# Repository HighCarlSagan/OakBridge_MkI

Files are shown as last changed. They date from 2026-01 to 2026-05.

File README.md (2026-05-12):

# OakBridge MkI

**A tactile PC dashboard — ESP32-S3, mechanical keys, IPS display, and a wooden enclosure.**







<p align="center">
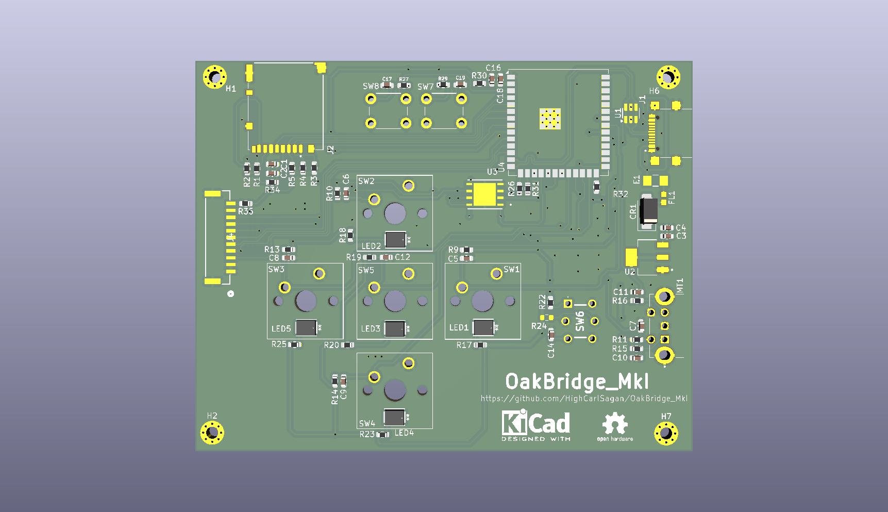
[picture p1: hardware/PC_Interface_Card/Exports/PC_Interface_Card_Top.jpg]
OakBridge MkI PCB - top view
  
  &nbsp;
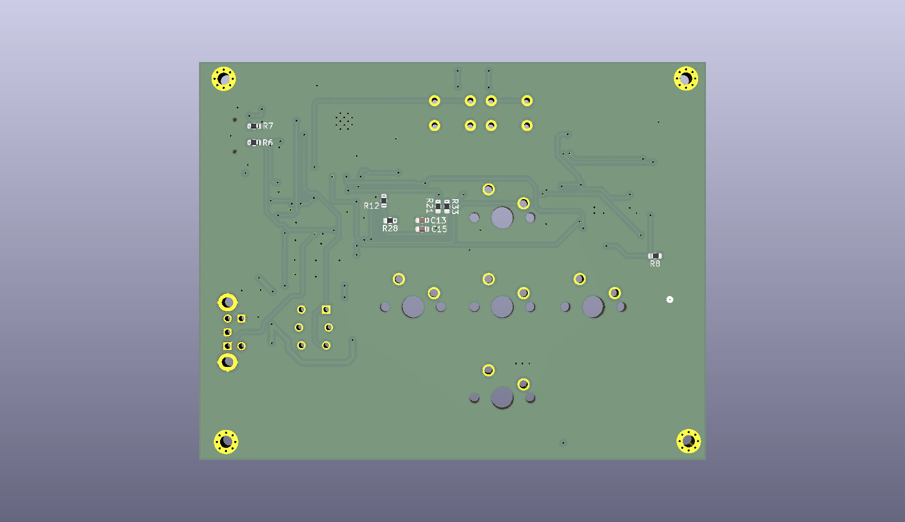
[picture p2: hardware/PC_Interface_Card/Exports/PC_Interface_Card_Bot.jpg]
OakBridge MkI PCB - bottom view
  
</p>

---

## Why I Built This

I spend a lot of my day staring at terminals and dashboards. I wanted a small, tactile thing on the desk that could show me what my PC was doing without me having to alt-tab to find out — CPU temp during a long compile, what's playing on Spotify, calendar at a glance — and let me poke at it with real keys instead of yet another window.

The other half of the motivation is the stretch. OakBridge is the first project where I deliberately scoped a hardware → firmware → host-software stack end-to-end, all on parts I hadn't used in anger before: ESP32-S3, LVGL on a real display, FRAM for state, and a Python companion talking over MQTT. The point is to do the whole loop once, badly, and have a tangible thing on the desk afterwards.

The name is a nod to **oak wood** (the planned enclosure) and a small shout-out to **Oak Ridge National Laboratory**.

---

## Initial Requirements

The table below tracks the design intent against what will ship on **v1.1** (the DRC-fixed respin currently in fab, expected back end of May 2026). The first soldered board — **v1.0** — never powered up; see [Lessons Learned](#lessons-learned-the-0mm-via-incident) for the story. Until v1.1 lands, all power-up-dependent outcomes are honestly marked **TBD**.

| # | Requirement | Target | Outcome (v1.1) |
|---|---|---|---|
| 1 | MCU with WiFi + BLE + USB + enough headroom for LVGL | ESP32-S3 class | ✅ ESP32-S3-WROOM-1-N16R8 (16 MB flash, 8 MB PSRAM) |
| 2 | Display | ≥3" IPS, ≥320×240, SPI | ✅ Waveshare 3.5" IPS 320×480 (touch fanned out but unused in MkI) |
| 3 | Tactile input | Real mechanical keys with backlighting | ✅ 5× Cherry MX2A-E1NA + per-key backlight LEDs |
| 4 | Analog input | Rotary encoder with push | ✅ CUI ACZ11 (12 PPR, integrated switch) |
| 5 | Non-volatile state across reboots | FRAM, ≥1 Mbit | ✅ MB85RS4MTYPN (4 Mbit SPI FRAM) |
| 6 | Local storage for assets / logs | MicroSD socket | ✅ Hirose DM3BT push-push socket |
| 7 | Single-cable host connection | USB-C, power + serial | ✅ USB-C 2.0 + CDC-ACM virtual COM |
| 8 | Front-end protection | ESD + reverse-polarity + EMI filtering + fuse | ✅ USBLC6-2SC6 + SS14 + BLM18PG600 + 1.5A fuse |
| 9 | Power | USB 5V in, single 3.3V rail | ✅ TLV1117LV33 LDO (1A capacity, ~400 mA budget) |
| 10 | Board size | Comfortably hand-held footprint | ✅ 92 × 70 mm, 2-layer FR-4 |
| 11 | Manufacturability | Common SMD, hand-solderable | ✅ 0603 passives, QFN regulator, through-hole switches |
| 12 | Power-on bring-up | All rails verified | ⏳ TBD (waiting on v1.1) |
| 13 | Display, switches, encoder, FRAM verified | Hardware sign-off | ⏳ TBD |
| 14 | Firmware: LVGL, MQTT, OTA, mDNS | End-to-end on real board | ⏳ TBD |
| 15 | Wooden enclosure | Oak / walnut, parametric CAD | 🔄 In progress, on backburner |

---

## Specifications

| | |
|---|---|
| **MCU** | Espressif ESP32-S3-WROOM-1-N16R8 (Xtensa LX7 dual-core, 16 MB flash, 8 MB PSRAM) |
| **Display** | Waveshare 3.5" IPS, 320 × 480, SPI (touch fanned out, not wired up in firmware) |
| **Keys** | 5 × Cherry MX2A-E1NA, per-key blue backlight (Cree JE2835) |
| **Encoder** | CUI ACZ11BR1E-15KQA1-12C, 12 PPR with push |
| **NV storage** | MB85RS4MTYPN — 4 Mbit SPI FRAM |
| **Removable storage** | Hirose DM3BT-DSF-PEJS — push-push microSD socket |
| **Host interface** | USB-C 2.0, power + CDC-ACM serial |
| **Front-end protection** | 1.5 A fuse → SS14 reverse-polarity Schottky → BLM18PG600 ferrite → USBLC6-2SC6 ESD array |
| **Regulator** | TI TLV1117LV33 — 3.3 V LDO, 1 A capacity |
| **Power budget** | ~400 mA typical (estimate; bring-up will measure) |
| **PCB** | 92 × 70 mm, 2-layer FR-4, 1.6 mm, 1 oz copper, ENIG |
| **Aux switches** | BOOT + EN (ESP32 strap-pull), one extra tactile for firmware-defined use |
| **Mounting** | 4 × M3 holes (H1, H2, H6, H7) |

---

## Architecture

```
                ┌──────────────────────────────────────────────┐
                │                  USB-C (J1)                  │
                │      5 V power + USB 2.0 (D+ / D−)           │
                └──────────────────┬───────────────────────────┘
                                   │
                          ┌────────┴───────────────┐
                          │  Protection front-end  │
                          │  Fuse → SS14 → Ferrite │
                          │     → USBLC6 ESD       │
                          └────────┬───────────────┘
                                   │ 5 V
                          ┌────────┴────────┐
                          │   TLV1117LV33   │
                          │   5 V → 3.3 V   │
                          └────────┬────────┘
                                   │ 3.3 V (1 A)
                                   │
        ┌──────────────────────────┼──────────────────────────┐
        │                          │                          │
        ▼                          ▼                          ▼
┌────────────────┐       ┌─────────────────────┐    ┌───────────────────┐
│ ESP32-S3 N16R8 │       │  Waveshare 3.5" IPS │    │  MB85RS4MTYPN     │
│  WiFi + BLE    │◀─────▶│   320×480, SPI      │    │  4 Mbit SPI FRAM  │
│  USB-OTG       │       │   JST-GH 11-pin (J4)│    │   (state, config) │
└───┬────────┬───┘       └─────────────────────┘    └───────────────────┘
    │        │
    │        │            ┌──────────────────────┐
    │        ├──────────▶ │  microSD (DM3BT, J2) │
    │        │            │  logs, assets        │
    │        │            └──────────────────────┘
    │        │
    │        │            ┌──────────────────────┐
    │        └──────────▶ │  5 × Cherry MX2A     │
    │                     │  + 5 × backlight LEDs│
    │                     │  + CUI ACZ11 encoder │
    │                     │  + BOOT / EN / aux   │
    │                     └──────────────────────┘
    │
    ▼   (over WiFi)
┌──────────────────────────────┐
│  PC companion (Python)       │
│  CPU / GPU / RAM / media     │
│  → MQTT broker → OakBridge   │
└──────────────────────────────┘
```

---

## Why X over Y

A handful of decisions on this board that had real alternatives. Capturing them here so future-me remembers the trade.

**ESP32-S3 over ESP32 / RP2040.** The S3 has native USB (no CH340), enough SRAM + PSRAM to make LVGL pleasant, hardware vector ops, and WiFi + BLE on-chip. RP2040 would have been cheaper and easier to program but every wireless feature would have become a bolt-on. ESP32 (original) lacks native USB and is starting to feel its age for new designs.

**FRAM over EEPROM or flash-only.** State on this board (last screen, brightness, key bindings, MQTT credentials) gets written often enough that flash endurance is a real concern, and EEPROM is too small / too slow for anything beyond a few config bytes. FRAM is essentially RAM-fast, byte-writable, and rated for 10¹³ writes. Worth the few extra dollars.

**MicroSD + FRAM, not just FRAM.** FRAM holds *state*; SD holds *content* (UI assets, fonts, logs, image slideshow). Different access patterns, different lifetimes, different sizes. Keeping them separate keeps the firmware honest about what's small-and-precious vs. large-and-replaceable.

**TLV1117LV33 LDO over a buck.** Total budget is ~400 mA at 3.3 V from a 5 V source. Worst-case dissipation is (5 − 3.3) × 0.4 ≈ 0.7 W — comfortable for a SOT-223 with a copper pour. A buck would have been ~10–15% more efficient at the cost of switching noise on the analog encoder input, a bigger BOM, and an inductor. Not worth it at this current.

**2-layer board, not 4-layer.** Cheap to fab and the signal count is low enough to route on two layers without pain. The trade I made — and paid for — was that USB differential routing on a 2-layer stackup is fussier than I respected. See [Lessons Learned](#lessons-learned-the-0mm-via-incident). MkII may go 4-layer just for the routing comfort, not because anything on this board needs it electrically.

**Cherry MX2A over original MX.** The MX2A generation has smoother factory lubing and a quieter sound profile, and the footprint is drop-in compatible with classic MX. Same keycap ecosystem, slightly nicer feel.

**Touch fanned out but unused.** The Waveshare 3.5" comes with capacitive touch on the same FPC. I fanned the touch lines out to the connector but didn't wire them into firmware for MkI. Wanted to keep the firmware scope tractable; physical keys are the primary interaction. Touch becomes a v2 / MkII concern.

---

## Key Components

| Ref | Part | Function |
|---|---|---|
| U4 | ESP32-S3-WROOM-1-N16R8 | MCU + WiFi/BLE module |
| U3 | MB85RS4MTYPN-GS | 4 Mbit SPI FRAM |
| U2 | TLV1117LV33DCYR | 3.3 V / 1 A LDO |
| U1 | USBLC6-2SC6 | USB ESD protection array |
| J1 | GSB1C41110SSHR | USB Type-C 2.0 receptacle (Amphenol) |
| J2 | DM3BT-DSF-PEJS | Push-push microSD socket (Hirose) |
| J4 | BM11B-GHS-TBT | JST GH 11-pin (display FPC fanout) |
| MT1 | ACZ11BR1E-15KQA1-12C | CUI rotary encoder, 12 PPR + push |
| SW1–SW5 | Cherry MX2A-E1NA | Mechanical key switches |
| SW6 | TL1240YQ2JBLK | Auxiliary tactile (firmware-defined) |
| SW7, SW8 | SW_Push (THT) | ESP32 BOOT and EN |
| LED1–LED5 | Cree JE2835ARY-N | Per-key backlight (blue) |
| CR1 | SS14 | Schottky reverse-polarity protection |
| F1 | 1.5 A fuse (C1Q-series) | Input over-current |
| FL1 | BLM18PG600SN1D | EMI ferrite bead |
| R6, R7 | 5.1 kΩ | USB-C CC pull-downs (UFP role) |
| R30, R33–R35 | 0 Ω | Config straps (boot mode / interface selection) |

Full BOM: [`hardware/PC_Interface_Card/Exports/PC_Interface_Card.csv`](hardware/PC_Interface_Card/Exports/PC_Interface_Card.csv)
Netlist: [`hardware/PC_Interface_Card/Exports/PC_Interface_Card.net`](hardware/PC_Interface_Card/Exports/PC_Interface_Card.net)

---

## Connector Pinout

| Connector | Type | Purpose |
|---|---|---|
| J1 — USB-C | Amphenol GSB1C41110SSHR | 5 V power in + USB 2.0 data (UFP, CC pull-downs to GND via 5.1 kΩ) |
| J2 — microSD | Hirose DM3BT push-push | SPI to ESP32 (CD line wired) |
| J4 — Display | JST GH 11-pin | SPI MOSI/SCLK + DC/CS/RST + backlight enable + touch (unused) |
| MT1 — Encoder | Through-hole | A / B / SW pins (pull-ups on host side) |
| H1 / H2 / H6 / H7 | M3 mounting | Mechanical only |

Detailed pin-by-pin mapping will live in [`docs/pinout.md`](docs/pinout.md) once firmware development starts and pin assignments are locked.

---

## Firmware

**Status: not started.** Waiting for v1.1 boards to arrive before writing a single line. The plan below is the design intent, not a description of code that exists.

**Framework:** ESP-IDF v5.x
**Location:** `firmware/` (currently empty)

**Planned scope:**

- **Display:** LVGL on top of the Waveshare SPI driver, double-buffered, target 30+ FPS on simple screens.
- **Input:** software-debounced switches; quadrature decode for the encoder; long-press / multi-press detection.
- **Storage:** FRAM holds runtime config (brightness, current screen, key bindings, MQTT credentials). microSD holds fonts, icons, and any image assets.
- **Connectivity:** WiFi station mode, mDNS responder as `oakbridge.local`, MQTT client to a user-configured broker, embedded HTTP config server, OTA over WiFi.
- **PC link:** MQTT topics — `oakbridge/stats` (incoming PC metrics), `oakbridge/media` (now-playing), `oakbridge/commands` (outgoing key/encoder events). QoS 1.

Firmware build and flash instructions will land in [`docs/firmware_guide.md`](docs/firmware_guide.md) (planned).

### PC Companion

**Status: placeholder.** No code yet. The repo has a `companion/` directory reserved for it.

**Plan:** Python 3.8+ daemon that collects CPU / GPU / RAM / temperature stats via `psutil` and `pynvml`, reads media-player state via MPRIS on Linux, and publishes everything to MQTT for OakBridge to render. Linux first (my daily driver); Windows / macOS later if there's appetite.

---

## Setup & Bring-up

(Filled in after v1.1 boards arrive and bring-up completes.)

**Planned bring-up sequence:**

| Step | Action | Pass criterion |
|---|---|---|
| 1 | Power on via USB-C, no MCU loaded | 3.3 V rail measures 3.27–3.33 V, no thermal events |
| 2 | Probe ESP32 strap pins at reset | BOOT/EN behave correctly, no unexpected boot mode |
| 3 | Flash a minimal "hello UART" firmware | CDC-ACM enumerates, serial output visible |
| 4 | LED smoke test | Each of LED1–LED5 lights when driven |
| 5 | Switch + encoder smoke test | All 5 MX keys + encoder A/B/SW register |
| 6 | FRAM read/write test | Known-pattern write → power cycle → read back matches |
| 7 | microSD enumerate + read | FAT32 mount succeeds, files listable |
| 8 | Display init | Waveshare 3.5" shows colour bars |
| 9 | LVGL "hello" screen | First UI screen renders, encoder navigates |
| 10 | WiFi join + MQTT publish loop | `oakbridge/heartbeat` visible on broker |

Empty results table for backfill once boards arrive:

| Step | Result | Date | Notes |
|---|---|---|---|
| 1 | TBD | | |
| 2 | TBD | | |
| 3 | TBD | | |
| 4 | TBD | | |
| 5 | TBD | | |
| 6 | TBD | | |
| 7 | TBD | | |
| 8 | TBD | | |
| 9 | TBD | | |
| 10 | TBD | | |

---

## Hardware

**KiCad project:** [`hardware/PC_Interface_Card/`](hardware/PC_Interface_Card/) (KiCad 9.0)
**Schematic PDF:** [`hardware/docs/schematic.pdf`](hardware/docs/schematic.pdf)
**Gerbers:** [`hardware/PC_Interface_Card/Exports/Gerbers/`](hardware/PC_Interface_Card/Exports/Gerbers/) (v1.1, planned for end-of-May 2026)
**BOM:** [`hardware/PC_Interface_Card/Exports/PC_Interface_Card.csv`](hardware/PC_Interface_Card/Exports/PC_Interface_Card.csv)

### PCB Specifications

- **Size:** 92 × 70 mm
- **Layers:** 2-layer FR-4, 1.6 mm
- **Copper:** 1 oz (35 µm) outer
- **Finish:** ENIG
- **Min trace / clearance:** 0.15 mm / 0.15 mm (6 mil / 6 mil)
- **USB differential pair:** 0.35 mm width, 0.15 mm gap, target 90 Ω
- **Vias (v1.1):** 0.6 mm pad / 0.3 mm drill (signal); 0.8 mm / 0.4 mm (power)
- **Stitching:** ~50 GND vias

Design rule references:
- [`hardware/docs/pcb_design_rules.md`](hardware/docs/pcb_design_rules.md)
- [`hardware/docs/usb_routing_quick_ref.txt`](hardware/docs/usb_routing_quick_ref.txt)
- [`hardware/docs/kicad_design_rules.json`](hardware/docs/kicad_design_rules.json)

### Enclosure

A wooden enclosure (oak) is planned. CAD work is in progress and on the backburner while the v1.1 PCB respin and firmware bring-up take priority. Parametric files will land in [`enclosure/`](enclosure/) once the design is ready.

---

## Lessons Learned: the 0mm-via incident

The v1.0 board does not work. It does not even power up — I haven't tried, because the failure is structural, not electrical.

**What happened.** When I set up the PCB design rules in KiCad, I left the **via drill diameter at 0 mm** in one of the via classes. KiCad's DRC would have caught this immediately. I skipped DRC verification before exporting Gerbers, because the layout was "obviously fine" — I had reviewed it visually and the renders looked clean. The fab took the files as-is, produced the board with pads where vias should have been, and shipped it. I soldered the whole thing before realising every via on the affected net class was just a copper dot with no hole through the board.

**What I'm doing about it.**

1. **v1.1 is in fab.** Same design, drill diameters corrected, going turnkey this time so I get a populated board back. Expected end of May 2026.
2. **DRC is no longer optional.** From now on, "DRC pass" is a step in my export checklist that has to be ticked before Gerbers leave my machine. I've added a one-line note to my KiCad project template.
3. **I review fab DFM reports.** Most fabs *do* run DFM checks and flag missing drills. This one didn't, or did and I missed the email. Either way, the responsibility is on me to verify, not on them to warn.

**Why this is in the README and not buried.** The whole point of these write-ups is to be honest about how the work actually went. The board is broken because I made an avoidable mistake. Documenting it costs me nothing and saves the next person (probably future-me, on a different project) from doing the same thing. It also makes everything *else* in this README more credible.

More detail in [`docs/lessons-learned.md`](docs/lessons-learned.md).

---

## Repository Structure

```
OakBridge_MkI/
├── hardware/
│   ├── PC_Interface_Card/         # KiCad 9.0 project
│   │   ├── PC_Interface_Card.kicad_pro
│   │   ├── PC_Interface_Card.kicad_sch
│   │   ├── PC_Interface_Card.kicad_pcb
│   │   ├── Libraries/             # Custom symbols + footprints
│   │   └── Exports/
│   │       ├── Gerbers/
│   │       ├── PC_Interface_Card.csv     # BOM
│   │       ├── PC_Interface_Card.net     # Netlist
│   │       ├── PC_Interface_Card_Top.jpg
│   │       └── PC_Interface_Card_Bot.jpg
│   └── docs/
│       ├── schematic.pdf
│       ├── pcb_design_rules.md
│       ├── usb_routing_quick_ref.txt
│       └── kicad_design_rules.json
├── firmware/                      # ESP-IDF project (planned)
├── companion/                     # Python PC companion (placeholder)
├── enclosure/                     # Oak enclosure CAD (in progress)
├── docs/
│   ├── lessons-learned.md
│   ├── firmware_guide.md          # planned
│   ├── pinout.md                  # planned
│   └── images/
├── LICENSE
└── README.md
```

---

## When to Use This / When NOT to Use This

**Use this if you want to:**
- Build a tactile, mechanical-key dashboard for your own PC, on your own desk, with your own UI.
- Learn ESP32-S3, LVGL, FRAM, and MQTT together on one small board.
- Fork the design as a starting point for any "small wireless gadget with a screen and a few buttons" project.

**Don't use this if you want to:**
- A polished, validated, production-ready product. This is a personal learning project. v1.0 didn't power up. v1.1 is in fab.
- A keyboard. 5 keys is not a keyboard. If you want a macropad, the Cherry MX footprints are reusable but you'd be better off with a project actually scoped as a macropad.
- A low-latency input device for gaming. USB-CDC + MQTT has latencies that are fine for "skip track" and bad for "fire weapon".

---

## Roadmap

### v1.0 — soldered, dud (May 2026)
PCBs fabricated and hand-soldered. Discovered the 0mm-via DRC miss after assembly. Never powered up. Kept on the desk as a reminder.

### v1.1 — DRC-fixed respin (end of May 2026, in fab)
- ✅ Drill diameters corrected, DRC clean, Gerbers re-exported
- ⏳ Turnkey assembly with the fab — boards arrive populated
- ⏳ Power-on bring-up (table above)
- ⏳ Firmware v0.1 — display init, switches, encoder, FRAM read/write
- ⏳ Firmware v0.2 — WiFi + MQTT + first PC-companion round-trip
- 🔄 Enclosure CAD (oak) — in progress, no committed date

### MkII — possibilities (much later, ~2027)

Not committed. Listing what I'd consider if I redesigned from scratch:

- 4-layer stackup for cleaner USB / display routing
- Capacitive touch wired into firmware (FPC fanout already exists)
- USB-C PD negotiation for higher current headroom
- Side-mount encoder for a flatter front face
- Independent RGB backlight per key (currently single-channel blue)

---

## License

**Hardware:** [CERN Open Hardware Licence Version 2 — Permissive (CERN-OHL-P-2.0)](LICENSE)
**Firmware** (when it exists): MIT
**Documentation:** CC-BY-4.0

You're free to use, modify, fabricate, and distribute the hardware design with attribution. No reciprocity required.

---

## Related Projects

- **[PC_and_Light_Controller](https://github.com/HighCarlSagan/PC_and_Light_Controller)** — sibling desk-control project. PC_and_Light_Controller handles physical switching of mains-powered desk devices; OakBridge handles the on-desk informational layer. Different problems, same desk.
- **[Dual_Power_Supply](https://github.com/HighCarlSagan/Dual_Power_Supply)** — my benchtop linear supply. The supply that probed v1.0 and confirmed the bad news.
- **[Carls_Homelab_Public](https://github.com/HighCarlSagan/Carls_Homelab_Public)** — where the MQTT broker will eventually live.

---

## Author

**Mayank S (HighCarlSagan)** — [GitHub @HighCarlSagan](https://github.com/HighCarlSagan) · [highcarlsagan.dev](https://highcarlsagan.dev)

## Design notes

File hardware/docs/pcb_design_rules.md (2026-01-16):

# OakBridge MkI PCB Design Rules & Guidelines

## Board Analysis Summary

### Key Components:
- **ESP32-S3-WROOM-1**: Main microcontroller (RF module)
- **USB-C Connector**: GSB1C41110SSHR (USB 2.0)
- **3.3V LDO**: TLV1117LV33 (1A)
- **FRAM**: MB85RS4MT (4Mbit SPI)
- **Display**: 3.5" Waveshare via 11-pin connector
- **Inputs**: 5x Cherry MX switches, rotary encoder, 3x tactile switches
- **LEDs**: 5x Cree JE2835 (with series resistors)
- **MicroSD**: Card connector

---

## LAYER STACK RECOMMENDATION: **2 LAYERS IS SUFFICIENT**

### Why 2 layers works:
✅ Single digital voltage domain (3.3V)
✅ Low-speed USB 2.0 (not high-speed USB)
✅ Low-frequency SPI communication (<50 MHz)
✅ No high-power analog circuits
✅ WiFi/BT RF contained within shielded module
✅ Good grounding achievable with careful ground plane design

### Cost-benefit:
- 2-layer: ~$5-20 for prototype (JLCPCB/PCBWay)
- 4-layer: ~$40-80 for same board
- No technical advantage justifies 4x cost increase for this design

---

## VIA SPECIFICATIONS

### Signal Vias (default):
- **Drill size**: 0.3mm (12 mil)
- **Annular ring**: 0.2mm (8 mil) minimum
- **Finished hole**: 0.3mm drill = ~0.28mm finished
- **Pad diameter**: 0.7mm (28 mil)
- **Use case**: All general signal routing

### Power Vias (USB +5V, +3.3V):
- **Drill size**: 0.4mm (16 mil)
- **Pad diameter**: 0.8mm (32 mil)
- **Quantity**: Multiple vias in parallel for power distribution
- **Spacing**: 2-3mm apart in power delivery paths
- **Use**: USB input, LDO output, ESP32 power pins

### Ground Stitching Vias:
- **Drill size**: 0.3mm (12 mil)
- **Pad diameter**: 0.7mm (28 mil)
- **Spacing**: Every 5-10mm along board perimeter
- **Quantity**: ~20-30 vias around board edge
- **Purpose**: Connect top/bottom ground planes, reduce EMI

### USB Shield Vias:
- **Drill size**: 0.5mm (20 mil)
- **Pad diameter**: 1.0mm (40 mil)
- **Placement**: 4x vias surrounding USB connector
- **Purpose**: Low impedance ground connection for shield

---

## TRACE WIDTH SPECIFICATIONS

### Power Traces:
```
+5V USB Input (up to 1A):
- Width: 0.6mm (24 mil) minimum
- Preferred: 0.8mm (32 mil)
- Temperature rise: <10°C @ 1A

+3.3V Rail (up to 800mA):
- Width: 0.5mm (20 mil) minimum
- Preferred: 0.6mm (24 mil)

LED Current (20-40mA per LED):
- Width: 0.2mm (8 mil) - adequate
- From resistors to LEDs
```

### Signal Traces:
```
Standard Digital I/O:
- Width: 0.15mm (6 mil) typical
- Spacing: 0.15mm (6 mil)
- SPI, I2C, GPIO: all 0.15mm is fine

High-frequency signals (if any):
- Width: 0.2mm (8 mil)
- Keep traces short
```

### Ground Planes:
```
- Pour on both layers
- Top layer: Split only where necessary
- Bottom layer: Solid continuous plane (ideal)
- Minimum clearance: 0.2mm (8 mil)
- Thermal relief: 0.5mm spoke width, 4 spokes
```

---

## USB 2.0 DIFFERENTIAL PAIR ROUTING

### USB D+/D- Specifications:
The USB-C connector provides USB 2.0 data:
- **Target impedance**: 90Ω differential (±10%)
- **Single-ended**: ~45Ω each

### Trace Dimensions (2-layer FR-4, 1.6mm thick):
```
Trace width: 0.35mm (14 mil)
Trace spacing (edge-to-edge): 0.15mm (6 mil)
Trace gap (center-to-center): 0.50mm (20 mil)
```

This achieves **~90Ω differential impedance** on standard FR-4:
- Er = 4.5
- H (dielectric height) = 1.6mm to bottom ground plane
- Calculate: Use Saturn PCB toolkit or KiCad calculator

### Critical USB Routing Rules:
1. **Keep D+ and D- paired**: Always route together
2. **Length matching**: ±2mm (±80 mil) maximum difference
3. **No vias if possible**: Route on single layer (top preferred)
4. **If vias needed**: Use both D+ and D- vias together, keep symmetrical
5. **Avoid 90° angles**: Use 45° or curved traces
6. **Keep away from**: 
   - Switching power traces (LDO input)
   - High-frequency digital signals (SPI CLK)
   - LED switching signals
7. **Ground reference**: Continuous ground plane underneath
8. **Trace length**: Keep <75mm (3 inches) total

### USB Connector Ground Strategy:
```
1. Four shield pins → direct via to ground plane (0.5mm vias)
2. GND pins → connect to ground pour
3. Add ground stitching vias around connector (every 2-3mm)
4. Ground guard traces on both sides of D+/D- pair
```

### Series Resistors (Already in schematic):
- **R6, R7**: 5.1kΩ on CC1, CC2 (correct for USB-C PD detection)
- Place **immediately adjacent** to USB connector
- No termination resistors needed on D+/D- for device-side

---

## COMPONENT-SPECIFIC LAYOUT GUIDELINES

### ESP32-S3-WROOM-1 Module:
```
Critical requirements:
1. Ground plane: Solid copper under entire module (both layers)
2. Keep-out zone: 15mm from antenna side (check datasheet)
3. Decoupling caps: Place C2, C4 as close as possible to 3V3 pin
4. SPI routing: Keep FRAM signals (CS, SCK, MOSI, MISO) <50mm
5. Boot/enable pullups: R1, R10 near module pins
```

### TLV1117LV33 LDO Regulator:
```
Input (VIN):
- C1 (1µF): Place <3mm from input pin
- Trace from USB: 0.6mm width minimum

Output (VOUT):
- C3 (1µF): Place <3mm from output pin
- Use multiple 0.4mm vias to distribute 3.3V

Ground:
- Large thermal pad on bottom layer
- Multiple vias (5-10x) connecting to bottom ground plane
- Thermal relief NOT recommended (need heat dissipation)
```

### USBLC6-2SC6 TVS Diode:
```
Placement:
- Must be between USB connector and ESP32
- Distance from USB connector: <10mm
- Route D+/D- through TVS before going to ESP32
- Ground pin: Direct via to ground plane (0.4mm via)

Routing:
  USB D+ → TVS I/O1 → ESP32 GPIO19
  USB D- → TVS I/O2 → ESP32 GPIO20
  TVS GND → Ground plane (low impedance)
```

### Cherry MX Switches (SW1-SW5):
```
Mechanical:
- Standard MX spacing: 19.05mm (0.75")
- PCB cutout: 14mm x 14mm
- Ensure adequate clearance for keycap travel

Electrical:
- Pull-up resistors: Already included (10kΩ)
- Debouncing: Software (GPIO inputs have hardware filters)
- Series resistors: 33Ω (R17, R19, R22, R23, R26) - correct!
```

### LED Routing:
```
Current-limiting resistors: 68Ω (R27, R30, R34) for 3 LEDs
                           33Ω for 2 LEDs (depends on color/current)

Placement:
- Resistor adjacent to LED (cathode side preferred)
- Trace width: 0.2mm adequate for <40mA
- Ground return: Use local ground plane
```

### MicroSD Card Slot:
```
SPI routing to ESP32:
- Keep all SPI traces <50mm
- Route on same layer (avoid vias)
- No need for matched lengths (low speed)
- Decoupling: C13 (1µF) near SD card power pin

Card detect switch:
- Pull-up already included in design
- Debounce in software
```

### Rotary Encoder (ACZ11BR1E):
```
Mounting:
- Through-hole component
- Ensure mechanical alignment with panel cutout

Routing:
- A, B, Common pins to ESP32 GPIOs
- Pull-ups: 10kΩ (R11, R12, R13)
- Shield connection: Ground via
- Debounce: Handle in firmware
```

---

## PCB DESIGN RULES (KiCad Settings)

### Design Rules → Constraints:
```
Minimum clearance: 0.15mm (6 mil)
Minimum track width: 0.15mm (6 mil)
Minimum via diameter: 0.7mm (28 mil)
Minimum via drill: 0.3mm (12 mil)
Minimum hole-to-hole: 0.5mm (20 mil)

Differential pairs (USB):
- Width: 0.35mm
- Gap: 0.15mm
- Max uncoupled: 0.5mm (design for 0.2mm)
```

### Design Rules → Pre-defined Sizes:
```
Via size #1 (Signal):
- Diameter: 0.7mm / Drill: 0.3mm

Via size #2 (Power):
- Diameter: 0.8mm / Drill: 0.4mm

Via size #3 (Ground stitching):
- Diameter: 0.7mm / Drill: 0.3mm

Track width #1 (Signal): 0.15mm
Track width #2 (Power 3.3V): 0.5mm
Track width #3 (Power 5V): 0.6mm
Track width #4 (USB diff): 0.35mm
```

### Board Setup → Physical Stackup:
```
2-Layer board:
- Total thickness: 1.6mm (standard)
- Copper weight: 1 oz (35µm) on both layers
- Core: FR-4 (Er ~4.5)
- Solder mask: Both sides (green/black/blue)
- Silkscreen: Both sides
- Surface finish: ENIG (gold) or HASL (lead-free)
```

### Solder Mask Expansion:
```
Solder mask expansion: 0.05mm (2 mil)
Solder paste shrinkage: 0.0mm (default)
Minimum web width: 0.1mm

For USB connector pads:
- Consider "solder mask defined" pads
- Prevents solder bridging on fine-pitch
```

---

## GROUNDING STRATEGY

### Two-Layer Ground Approach:
```
TOP LAYER (Component side):
- Ground pour with splits around:
  * USB differential pair
  * High-current power traces
  * RF antenna keep-out zone
- Connect pour to bottom ground with stitching vias

BOTTOM LAYER (Solder side):
- Solid continuous ground plane (IDEAL)
- No splits except for specific isolation
- Main return path for all signals
- ESP32 module sits over solid ground
```

### Ground Stitching Pattern:
```
Via placement:
1. Around board perimeter: Every 5-10mm
2. Under ESP32 module: 10-15 vias
3. Around USB connector: 6-8 vias
4. Between power sections: 3-5 vias
5. Near high-speed signals: Every 10mm along trace

Total ground vias: ~40-60 for typical board size
```

### Ground Connection Priority:
```
1. USB shield → Ground (0.5mm vias, 4x)
2. LDO thermal pad → Ground (0.4mm vias, 8x)
3. ESP32 GND pins → Ground (0.3mm vias, 4x)
4. Bypass cap grounds → Ground (0.3mm vias, 1-2x each)
5. Connector shields → Ground
```

---

## MANUFACTURING & ASSEMBLY NOTES

### Fabrication Specifications (JLCPCB/PCBWay):
```
Board size: Measure actual (likely <100x100mm)
Layers: 2
Thickness: 1.6mm
Min track/space: 6/6 mil (0.15/0.15mm)
Min hole size: 0.3mm
Copper weight: 1 oz
Surface finish: ENIG preferred (better for RF/USB)
Solder mask color: Your choice
Silkscreen: White on dark, black on light
```

### Panelization:
```
If ordering multiple boards:
- Add mouse bites or V-grooves
- Keep 5mm border around board edge
- Tooling holes: 4x at corners
```

### Assembly Recommendations:
```
1. Reflow profile for 0603 components: Standard SAC305
2. Stencil thickness: 0.12mm (standard)
3. Paste release: 1:1 ratio (stencil holes = pads)
4. Order: 
   a. Reflow SMD components
   b. Hand-solder through-hole (switches, encoder, connectors)
```

### Special Considerations:
```
- ESP32 module: Pre-assembled, reflow once only
- Cherry MX switches: Hand solder after SMD reflow
- USB-C connector: Verify alignment before soldering
- MicroSD slot: Correct orientation critical
- Display connector: Pin 1 alignment
```

---

## DESIGN RULE CHECK (DRC) SETTINGS

### Critical Checks:
```
✅ Clearance violations
✅ Track width violations
✅ Via size violations
✅ Hole-to-hole spacing
✅ Copper-to-edge clearance (0.5mm min)
✅ Silkscreen-to-pad clearance (0.15mm)
✅ Courtyard overlap (component collision)
✅ Unconnected pads
✅ Missing traces
```

### Electrical Rules Check (ERC):
```
✅ Power pins connected
✅ Pull-ups/downs present
✅ Unused inputs tied to valid logic levels
✅ Decoupling caps on all power pins
✅ Crystal loading caps (N/A - using internal oscillator)
✅ Reset/boot circuitry correct
```

---

## IMPEDANCE CALCULATIONS (Reference)

### USB Differential Impedance:
For 2-layer board (1.6mm FR-4, 1oz copper):
```
W = 0.35mm (trace width)
S = 0.15mm (edge-to-edge spacing)
H = 1.6mm (height to ground plane)
Er = 4.5 (FR-4)

Calculated Zdiff ≈ 88-92Ω ✅ (target: 90Ω ±10%)
```

Verify using:
- KiCad PCB Calculator (Tools → Calculator)
- Saturn PCB Toolkit
- Online calculator: https://www.eeweb.com/tools/differential-stripline-impedance/

---

## TESTING & VALIDATION CHECKLIST

### Pre-Assembly Tests:
```
□ Visual inspection: No short circuits, clean pads
□ Continuity test: Power rails isolated from ground
□ USB connector: No shorts between D+, D-, VBUS, GND
```

### Post-Assembly Tests:
```
□ Power-on test: Measure 5V at USB input
□ LDO output: Verify 3.3V ±3%
□ ESP32 boot: Check via serial (EN button + GPIO0)
□ USB enumeration: Device appears on PC
□ LED test: All LEDs functional
□ Switch test: All switches register
□ MicroSD: Card detect and SPI communication
□ Display: SPI communication and display init
□ Encoder: A/B phase signals
```

---

## RECOMMENDED LAYOUT WORKFLOW

1. **Placement** (Most critical step):
   - USB connector on board edge
   - ESP32 in center region
   - LDO near USB input
   - TVS diode between USB and ESP32
   - MicroSD slot near ESP32 SPI pins
   - Switches arranged ergonomically
   - LEDs visible from front panel

2. **Power routing** (Do this first):
   - 5V from USB to LDO input
   - 3.3V from LDO to all components
   - Multiple vias for power distribution
   - Ground plane on both layers

3. **Critical signal routing**:
   - USB D+/D- differential pair (0.35mm, 0.15mm gap)
   - SPI signals (FRAM, MicroSD)
   - Display connector signals

4. **General signals**:
   - Switch inputs
   - LED outputs
   - Encoder signals

5. **Ground plane pour**:
   - Top layer: Pour with keepouts
   - Bottom layer: Solid pour
   - Add stitching vias (~50 total)

6. **Silkscreen**:
   - Component references
   - Pin 1 indicators
   - Polarity markers
   - Version number
   - Your logo/name

7. **Final checks**:
   - DRC: Zero errors
   - Visual inspection
   - 3D view verification
   - Gerber preview

---

## COST ESTIMATES (2025 Prices)

### PCB Fabrication:
```
2-layer, 100x100mm, 1.6mm, ENIG:
- JLCPCB: $5 for 5 boards + shipping (~$20-30 total)
- PCBWay: Similar pricing
- OSH Park: ~$5/sq.in × area (~$25-35 total)

Turnaround:
- Standard: 7-10 days
- Express: 3-5 days (+50% cost)
```

### Component Assembly (if using JLCPCB):
```
Basic SMD assembly: ~$15-30
+ Extended parts library: +$3/part type
+ Setup fee: $8
Total BOM cost: ~$50-80 (depends on parts)

Hand assembly recommended for this design:
- Through-hole switches
- Display connector
- USB connector (easier by hand)
```

---

## FILES TO GENERATE FOR MANUFACTURING

### Required Gerber Files:
```
- F.Cu (Top copper)
- B.Cu (Bottom copper)
- F.Mask (Top solder mask)
- B.Mask (Bottom solder mask)
- F.Silkscreen (Top silkscreen)
- B.Silkscreen (Bottom silkscreen)
- Edge.Cuts (Board outline)
- F.Paste (Top solder paste)
- B.Paste (Bottom solder paste)

Drill files:
- .drl (Excellon drill file)
- PTH and NPTH separate or combined
```

### Additional Files:
```
- BOM (CSV or Excel)
- CPL/PnP (Pick-and-place coordinates)
- Assembly drawing (PDF)
- Schematic (PDF)
- 3D model (STEP file - for enclosure design)
```

---

## FINAL RECOMMENDATIONS

### For your OakBridge MkI design:

✅ **Use 2 layers** - No technical need for 4 layers
✅ **Standard vias** (0.7mm/0.3mm drill) work fine
✅ **USB impedance**: 0.35mm traces, 0.15mm gap → 90Ω
✅ **Power traces**: 0.5-0.6mm adequate for currents involved
✅ **Ground plane**: Bottom layer solid, top layer poured
✅ **Total cost**: ~$30-50 for 5 prototype boards

### Next Steps:
1. Apply these design rules in KiCad
2. Complete component placement
3. Route critical signals (USB, power, SPI)
4. Route remaining signals
5. Pour ground planes
6. Add ground stitching vias
7. Run DRC (fix all errors)
8. Generate Gerbers
9. Order from JLCPCB/PCBWay

Good luck with your layout! 🚀

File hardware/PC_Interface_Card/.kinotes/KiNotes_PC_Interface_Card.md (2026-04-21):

# **PC_Interface_Card - Design Notes**

## **Overview**
<!-- Brief description of the PCB project -->

## **Schematic Notes**
<!-- Key circuit blocks, design rationale -->

## **Layout Considerations**
<!-- Layer stackup, impedance, keep-outs -->

## **Component Notes**
<!-- Click on designators like R1, C5, U3 to highlight on PCB -->

## **Power Distribution**
<!-- Power rails, decoupling strategy -->

## **Signal Integrity**
<!-- Critical nets, routing constraints -->

## **References**
<!-- Datasheets, application notes, calculations -->

---
*KiNotes - PCBtools.xyz*

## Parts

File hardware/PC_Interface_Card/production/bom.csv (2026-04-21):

Designator | Footprint | Quantity | Value | LCSC Part #
C1, C13, C16, C3 | 0603 | 4 | 1u_50V_0603 | C15849
C10, C11, C12, C14, C15, C17, C18, C19, C2, C4, C5, C6, C7, C8, C9 | 0603 | 15 | 100n_50V_0603 | C14663
CR1 | D_SMA | 1 | SS14 | C2480
F1 | C1_BEL-M | 1 | C1Q 1.5
FL1 | BEAD_BLM18PG_C1608X95N | 1 | BLM18PG600SN1D
J1 | AMPHENOL_GSB1C41110SSHR | 1 | GSB1C41110SSHR
J2 | HRS_DM3BT-DSF-PEJS | 1 | DM3BT-DSF-PEJS
J4 | CONN11_BM11B-GHS-TBTLFSNN_JST | 1 | BM11B-GHS-TBT
LED1, LED2, LED3, LED4, LED5 | LED_JE2835_CRW-M | 5 | LED_Cree_JE2835
MT1 | XDCR_ACZ11BR1E-15KQA1-12C | 1 | ACZ11BR1E-15KQA1-12C
R1, R10, R11, R12, R13, R14, R15, R16, R19, R2, R21, R22, R26, R27, R28, R29, R3, R31, R32, R4, R5, R8, R9 | 0603 | 23 | 10k_0.1W_0603 | C25804
R17, R18, R20, R23, R25 | 0603 | 5 | 33R_0.1W_0603 | C23140
R24 | 0603 | 1 | 68R_0.2W_0603
R30, R33, R34, R35 | 0603 | 4 | 0R_0.1W_0603 | C21189
R6, R7 | 0603 | 2 | 5.1k_0.1W_0603 | C23186
SW1, SW2, SW3, SW4, SW5 | CherryMX_1.00u_PCB | 5 | CherryMX
SW6 | TL1240YQ | 1 | TL1240YQ2JBLK
SW7, SW8 | SW_PUSH_6mm | 2 | SW_Push
U1 | SOT-23-6 | 1 | USBLC6-2SC6
U2 | VREG_TLV1117LV33DCYR | 1 | TLV1117LV33DCYR
U3 | DFN8_FUJ-M | 1 | MB85RS4MTYPN-GS-AWEWE1
U4 | ESP32-S3-WROOM-1U | 1 | ESP32-S3-WROOM-1 | C2913202

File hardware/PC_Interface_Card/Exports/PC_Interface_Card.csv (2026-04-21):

Reference | Qty | Value | DNP | Exclude from BOM | Exclude from Board | Footprint | Datasheet | Manufacturer | Manufacturer Part Number | Description | LCSC
C1,C3,C13,C16 | 4 | 1u_50V_0603 |  |  |  | Capacitor_SMD:C_0603_1608Metric | https://jlc-prod-smt.oss-eu-central-1.aliyuncs.com/smtDataManualFile/8556213788455567360-C15849.pdf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 | KEMET | C0603C105K4RACTU | 1uF 50V X5R ±10% 0603 Multilayer Ceramic Capacitors MLCC - SMD/SMT ROHS | C15849
C2,C4,C5,C6,C7,C8,C9,C10,C11,C12,C14,C15,C17,C18,C19 | 15 | 100n_50V_0603 |  |  |  | Capacitor_SMD:C_0603_1608Metric | https://jlc-prod-smt.oss-eu-central-1.aliyuncs.com/smtDataManualFile/8556213788455567360-C15849.pdf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 | YAGEO | CC0603KRX7R7BB104 | 100nF 50V X7R ±10% 0603 Multilayer Ceramic Capacitors MLCC - SMD/SMT ROHS | C14663
CR1 | 1 | SS14 |  |  |  | Diode_SMD:D_SMA | https://jlc-prod-smt.oss-eu-central-1.aliyuncs.com/smtDataManualFile/8579710789134958592-C2480.pdf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 | Onsemi | SS14 | -55℃~+150℃ 1A 25A 300uA@40V 40V 550mV@1A Independent SMA(DO-214AC) Schottky Diodes ROHS | C2480
F1 | 1 | C1Q 1.5 | DNP |  |  | Footprint:C1_BEL-M | https://www.digikey.in/en/products/detail/bel-fuse-inc/C1Q-1-5/615158 | Bel Fuse | C1Q 1.5 | 1.5 A 125 V 63 V Fuse Board Mount (Cartridge Style Excluded) Surface Mount 1206 (3216 Metric)
FL1 | 1 | BLM18PG600SN1D | DNP |  |  | Footprint:BEAD_BLM18PG_C1608X95N | https://www.murata.com/en-us/products/productdata/8796738650142/ENFA0003.pdf | Murata | BLM18PG600SN1D | 60 Ohms @ 100 MHz 1 Power Line Ferrite Bead 0603 (1608 Metric) 500mA 100mOhm
J1 | 1 | GSB1C41110SSHR | DNP |  |  | Footprint:AMPHENOL_GSB1C41110SSHR | https://cdn.amphenol-cs.com/media/wysiwyg/files/documentation/datasheet/inputoutput/io_usb_2_0_type_c_lite.pdf | Amphenol | GSB1C41110SSHR | USB-C (USB TYPE-C) USB 2.0 Receptacle Connector 24 (16+8 Dummy) Position Surface Mount, Right Angle; Through Hole
J2 | 1 | DM3BT-DSF-PEJS | DNP |  |  | Footprint_Project_PC_Interface:HRS_DM3BT-DSF-PEJS | https://www.hirose.com/product/download/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 | Hirose | DM3BT-DSF-PEJS | 10 (8 + 2) Position Card Connector Secure Digital - microSD™ Surface Mount, Right Angle Gold
J3,J5 | 2 | GHR-11V-S | DNP |  | Excluded from board |  | https://www.jst-mfg.com/product/pdf/eng/eGH.pdf | JST Sales America Inc. | GHR-11V-S | 11 Rectangular Connectors - Housings Receptacle Natural 0.049" (1.25mm)
J4 | 1 | BM11B-GHS-TBT | DNP |  |  | Footprint_Project_PC_Interface:CONN11_BM11B-GHS-TBTLFSNN_JST |  | JST Sales America Inc. | BM11B-GHS-TBT | Generic connector, single row, 01x13, script generated
LED1,LED2,LED3,LED4,LED5 | 5 | LED_Cree_JE2835 |  |  |  | Footprint:LED_JE2835_CRW-M | https://downloads.cree-led.com/files/ds/j/JSeries-2835-Color.pdf | Cree LED | JE2835ARY-N-0002A0000-N0000001 | LED Lighting Color J Blue 455nm (450nm ~ 460nm) 1411 (3528 Metric)
MD1 | 1 | WaveShare 3.5" RPi LCD (G) | DNP |  | Excluded from board |  | https://www.waveshare.com/wiki/3.5inch_RPi_LCD_(G) | Waveshare | 30897 | 3.5inch Resistive Touch Display (G) for Raspberry Pi, IPS Panel, 320×480 Resolution, Immersion Gold Process, 262K Color
MK1 | 1 | OEDNI-75-4-7 | DNP |  | Excluded from board |  | https://static1.squarespace.com/static/54efb6f4e4b0d7862a93d7f5/t/57b3baa8cd0f68856d468c76/1471396521494/OED_PNB_fv3_v.png | Kilo International | OEDNI-75-4-7 | Knurled, Diamond Knob 0.236" (6.00mm) Shaft with Metal Black Matte
MT1 | 1 | ACZ11BR1E-15KQA1-12C | DNP |  |  | Footprint:XDCR_ACZ11BR1E-15KQA1-12C | https://www.cuidevices.com/product/resource/acz11.pdf | Same Sky (Formerly CUI Devices) | ACZ11BR1E-15KQA1-12C | Rotary Encoder Incremental 12 Quadrature (Incremental) Right Angle
R1,R2,R3,R4,R5,R8,R9,R10,R11,R12,R13,R14,R15,R16,R19,R21,R22,R26,R27,R28,R29,R31,R32 | 23 | 10k_0.1W_0603 |  |  |  | Resistor_SMD:R_0603_1608Metric | https://jlc-prod-smt.oss-eu-central-1.aliyuncs.com/smtDataManualFile/8579706381316128768-C25804.pdf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 | Panasonic Electronic Components | ERJ-PB3B1002V | -55℃~+155℃ 100mW 10kΩ 75V Thick Film Resistor ±1% ±100ppm/℃ 0603 Chip Resistor - Surface Mount ROHS | C25804
R6,R7 | 2 | 5.1k_0.1W_0603 |  |  |  | Resistor_SMD:R_0603_1608Metric | https://jlc-prod-smt.oss-eu-central-1.aliyuncs.com/smtDataManualFile/8579706277020426240-C23186.pdf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 | Panasonic Electronic Components | ERJ-PB3B5101V | -55℃~+155℃ 100mW 5.1kΩ 75V Thick Film Resistor ±1% ±100ppm/℃ 0603 Chip Resistor - Surface Mount ROHS | C23186
R17,R18,R20,R23,R25 | 5 | 33R_0.1W_0603 |  |  |  | Resistor_SMD:R_0603_1608Metric | https://jlc-prod-smt.oss-eu-central-1.aliyuncs.com/smtDataManualFile/8579706226135130112-C23140.pdf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 | TE Connectivity Passive Product | CRGH0603J33R | -55℃~+155℃ 100mW 33Ω 75V Thick Film Resistor ±1% ±100ppm/℃ 0603 Chip Resistor - Surface Mount ROHS | C23140
R24 | 1 | 68R_0.2W_0603 | DNP |  |  | Resistor_SMD:R_0603_1608Metric | https://www.yageogroup.com/content/datasheet/asset/file/PYU-RC_GROUP_51_ROHS_L | YAGEO | RC0603FR-7W68RL | 68 Ohms ±1% 0.2W, 1/5W Chip Resistor 0603 (1608 Metric) Moisture Resistant Thick Film
R30,R33,R34,R35 | 4 | 0R_0.1W_0603 |  |  |  | Resistor_SMD:R_0603_1608Metric | https://jlc-prod-smt.oss-eu-central-1.aliyuncs.com/smtDataManualFile/8578255895085699072-C21189.pdf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 |  |  | -55℃~+155℃ 0Ω 100mW 75V Thick Film Resistor ±1% 0603 Chip Resistor - Surface Mount ROHS | C21189
SW1,SW2,SW3,SW4,SW5 | 5 | CherryMX | DNP |  |  | CherryMX_PCB:CherryMX_1.00u_PCB | https://cherry.saas.contentserv.com/admin/rest/document/30?ContextIDs=22889&Language=1 | Cherry Americas LLC | MX2A-E1NA | Pushbutton Switch SPST-NO Keyswitch, Illuminated Through Hole
SW6 | 1 | TL1240YQ2JBLK | DNP |  |  | Footprint:TL1240YQ | https://configured-product-images.s3.amazonaws.com/Datasheets/TL1240.pdf | E Switch | TL1240YQ2JBLK | Tactile Switch SPST-NO Top Actuated Through Hole
SW7,SW8 | 2 | SW_Push | DNP |  |  | Button_Switch_THT:SW_PUSH_6mm |  |  |  | Push button switch, generic, two pins
U1 | 1 | USBLC6-2SC6 | DNP |  |  | Package_TO_SOT_SMD:SOT-23-6 | https://www.st.com/resource/en/datasheet/cd00050750.pdf | STMicroelectronics | USBLC6-2SC6 | 17V Clamp 5A (8/20µs) Ipp Tvs Diode Surface Mount SOT-23-6
U2 | 1 | TLV1117LV33DCYR | DNP |  |  | Footprint:VREG_TLV1117LV33DCYR | https://www.ti.com/general/docs/suppproductinfo.tsp?distId=10 | Texas Instruments | TLV1117LV33DCYR | Linear Voltage Regulator IC Positive Fixed 1 Output 1A SOT-223-4
U3 | 1 | MB85RS4MTYPN-GS-AWEWE1 | DNP |  |  | Footprint:DFN8_FUJ-M | https://www.ramxeed.com/assets/images/products/datasheet/FeRAM/s2/MB85RS4MTY-DS3v0-E.pdf | Ramxseed | MB85RS4MTYPF-G-BCE1 | FRAM (Ferroelectric RAM) Memory IC 4Mbit SPI 50 MHz 8-SOP
U4 | 1 | ESP32-S3-WROOM-1 |  |  |  | RF_Module:ESP32-S3-WROOM-1U | https://www.espressif.com/sites/default/files/documentation/esp32-s3-wroom-1_wroom-1u_datasheet_en.pdf | Espressif | ESP32-S3-WROOM-1-N16R8 | Bluetooth, WiFi 802.11b/g/n, Bluetooth v5.0 Transceiver Module 2.4GHz PCB Trace Surface Mount | C2913202

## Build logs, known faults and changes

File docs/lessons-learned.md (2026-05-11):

# Lessons Learned

A standing log of things this project taught me — kept here so future-me reads it before starting the next board.

---

## 1. The 0mm-via incident (v1.0, May 2026)

### The mistake

When I configured the KiCad project's via classes for OakBridge MkI, I left the **drill diameter at 0 mm** on one class. KiCad represents this as "use the rule from the class," and the class happened to inherit a 0 value that I never overrode.

This is exactly the kind of thing DRC exists to catch. KiCad's DRC would have flagged it in a single line.

### Why it shipped anyway

Three failures stacked:

1. **I skipped DRC before export.** The layout *looked* clean in the 3D renders and after a visual board-edge check. I told myself a final DRC pass was a formality and went straight to Gerber export.
2. **The fab did not flag it.** Most fabs run a DFM (Design for Manufacturing) review that catches structurally impossible features — a via with 0 mm drill is one of them. Either this fab didn't run that check, ran it and didn't surface a flag, or surfaced a flag I missed in the order confirmation email.
3. **I assembled before testing.** I soldered the whole board, including the ESP32 module, before checking continuity through any of the vias on the affected net class. By the time I noticed, the components were committed to a dud PCB.

### How I noticed

Continuity test between two pads that should have been on the same net read open. Probing a via pad on the same net read the via pad itself, but not the other side of the board. Held the bare side of the board to a light — pads, no holes.

### The cost

- One PCB order (5× boards from a prototype fab, ~$30 shipped)
- One BOM order (~$80 in unique components — ESP32 module, FRAM, display socket, Cherry MX × 5, encoder, USB-C)
- One Saturday of careful hand-soldering (~6 hours)
- The hit to my "yeah I know what I'm doing" ego

Total: roughly $110 and a day. As tuition for "always run DRC," it's cheap. At work, the same mistake on a flight board would cost an order of magnitude more and a schedule slip.

### What changed

Three concrete changes, all small, all permanent:

1. **DRC is now an export gate.** My personal KiCad project checklist now reads:
   - [ ] Run DRC. Zero violations, zero unresolved warnings.
   - [ ] Run electrical rules check (ERC).
   - [ ] Generate Gerbers.
   - [ ] Generate drill files.
   - [ ] Verify drill file in a separate viewer (not the same KiCad instance).
   - [ ] Open the Gerbers in `gerbview` and visually confirm drill layer alignment.
   - [ ] Then — and only then — submit to the fab.

2. **I read the DFM report.** Every fab order from now on, I open the DFM/DRC report the fab sends back *before* approving the production run, not after. If they don't send one, I ask.

3. **No assembly before continuity sanity check.** Before any SMD reflow on a new spin, a quick continuity sweep on three or four representative nets — power, ground, USB D+/D−, and one signal that should route through a via. Takes five minutes, catches structural failures.

### Why it's in the public README

Because the alternative is pretending the project went smoothly and that I built it on the first try. That's not what happened. Owning the mistake explicitly is the honest version and also — practically — the version that helps anyone else who's about to skip DRC for the same reason I did. If this note saves one person one Saturday, it has paid for itself.

---

## 2. Touch wired but unused

Decided late in the layout that wiring the capacitive touch lines from the Waveshare 3.5" was free (the FPC fans them out anyway) and shipping firmware support for them was *not* free. So the lines are on the board, terminated correctly, and the firmware ignores them.

The lesson is the principle: **route the optional input, defer the firmware**. The pin-out cost is sunk now; if I ever want touch in v2 or in a fork, the hardware already supports it.

This generalises: if a feature is cheap on the PCB and expensive in firmware, ship the hardware and skip the firmware. The reverse — committing the firmware before the hardware exists — is the path to vapourware.

---

## 3. Single-channel backlight is fine, actually

I considered RGB backlighting per key (WS2812B-2020 under each switch, daisy-chained). Rejected it for MkI because:

- One data line, one timing-sensitive protocol, one more thing to debug at bring-up.
- 5× independent blue LEDs with individual current-limit resistors gives me per-key on/off control via GPIO, which is 90% of what backlight actually needs to do.
- The aesthetic I'm going for ("warm wood + a few blue glows") doesn't want a rainbow.

If I'd been designing for community appeal rather than my own desk, the answer might be different. But the project is mine and the call was right for the scope.

---

*This file is a running log. Updated as new lessons turn up.*

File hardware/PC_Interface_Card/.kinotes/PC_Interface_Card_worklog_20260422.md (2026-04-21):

# Work Log — PC_Interface_Card
**Total: 0h 0m**

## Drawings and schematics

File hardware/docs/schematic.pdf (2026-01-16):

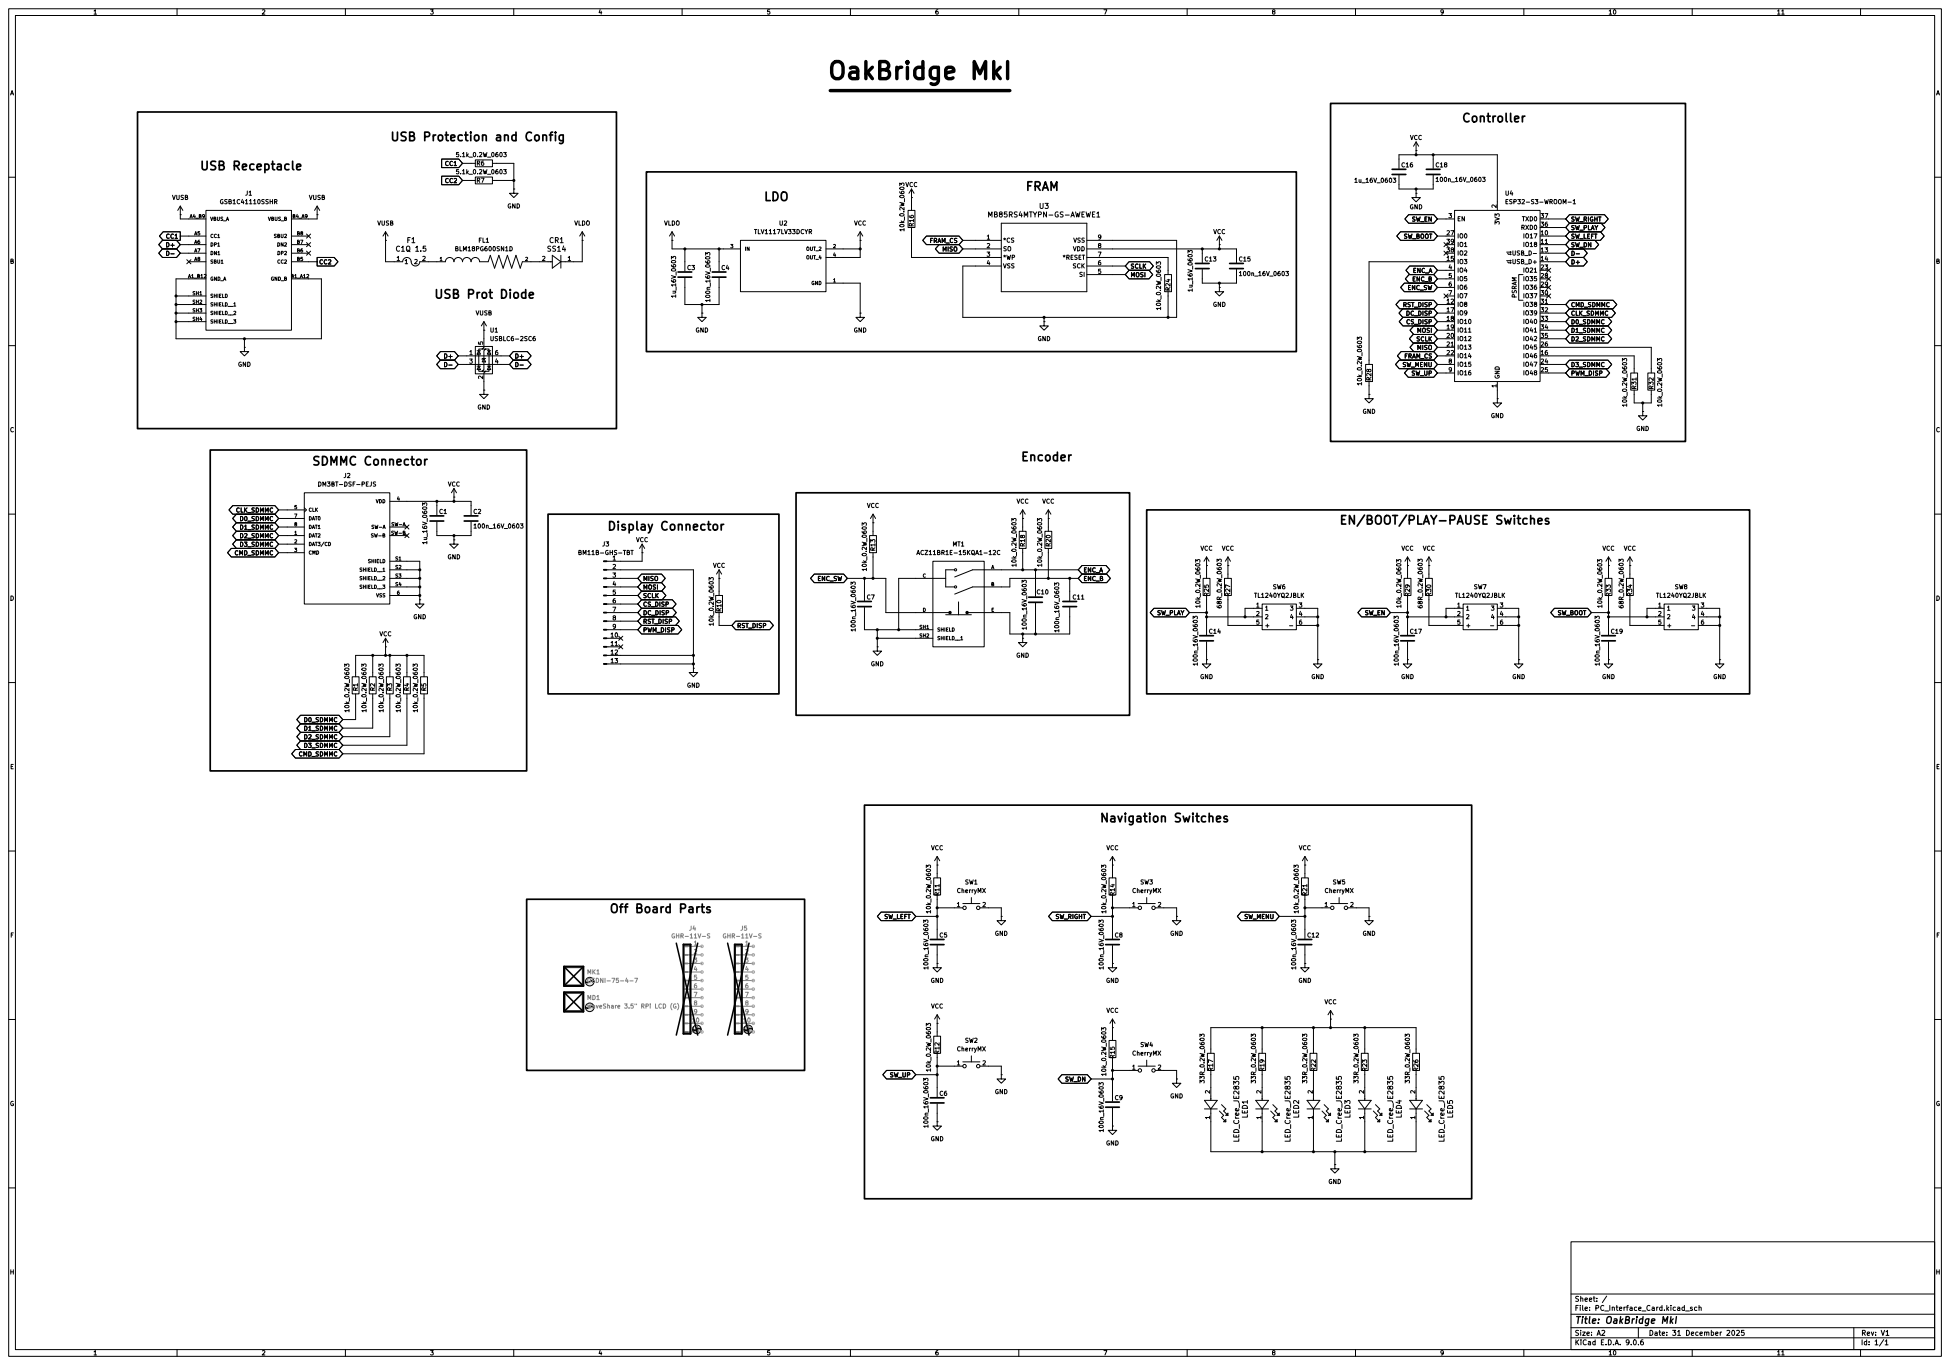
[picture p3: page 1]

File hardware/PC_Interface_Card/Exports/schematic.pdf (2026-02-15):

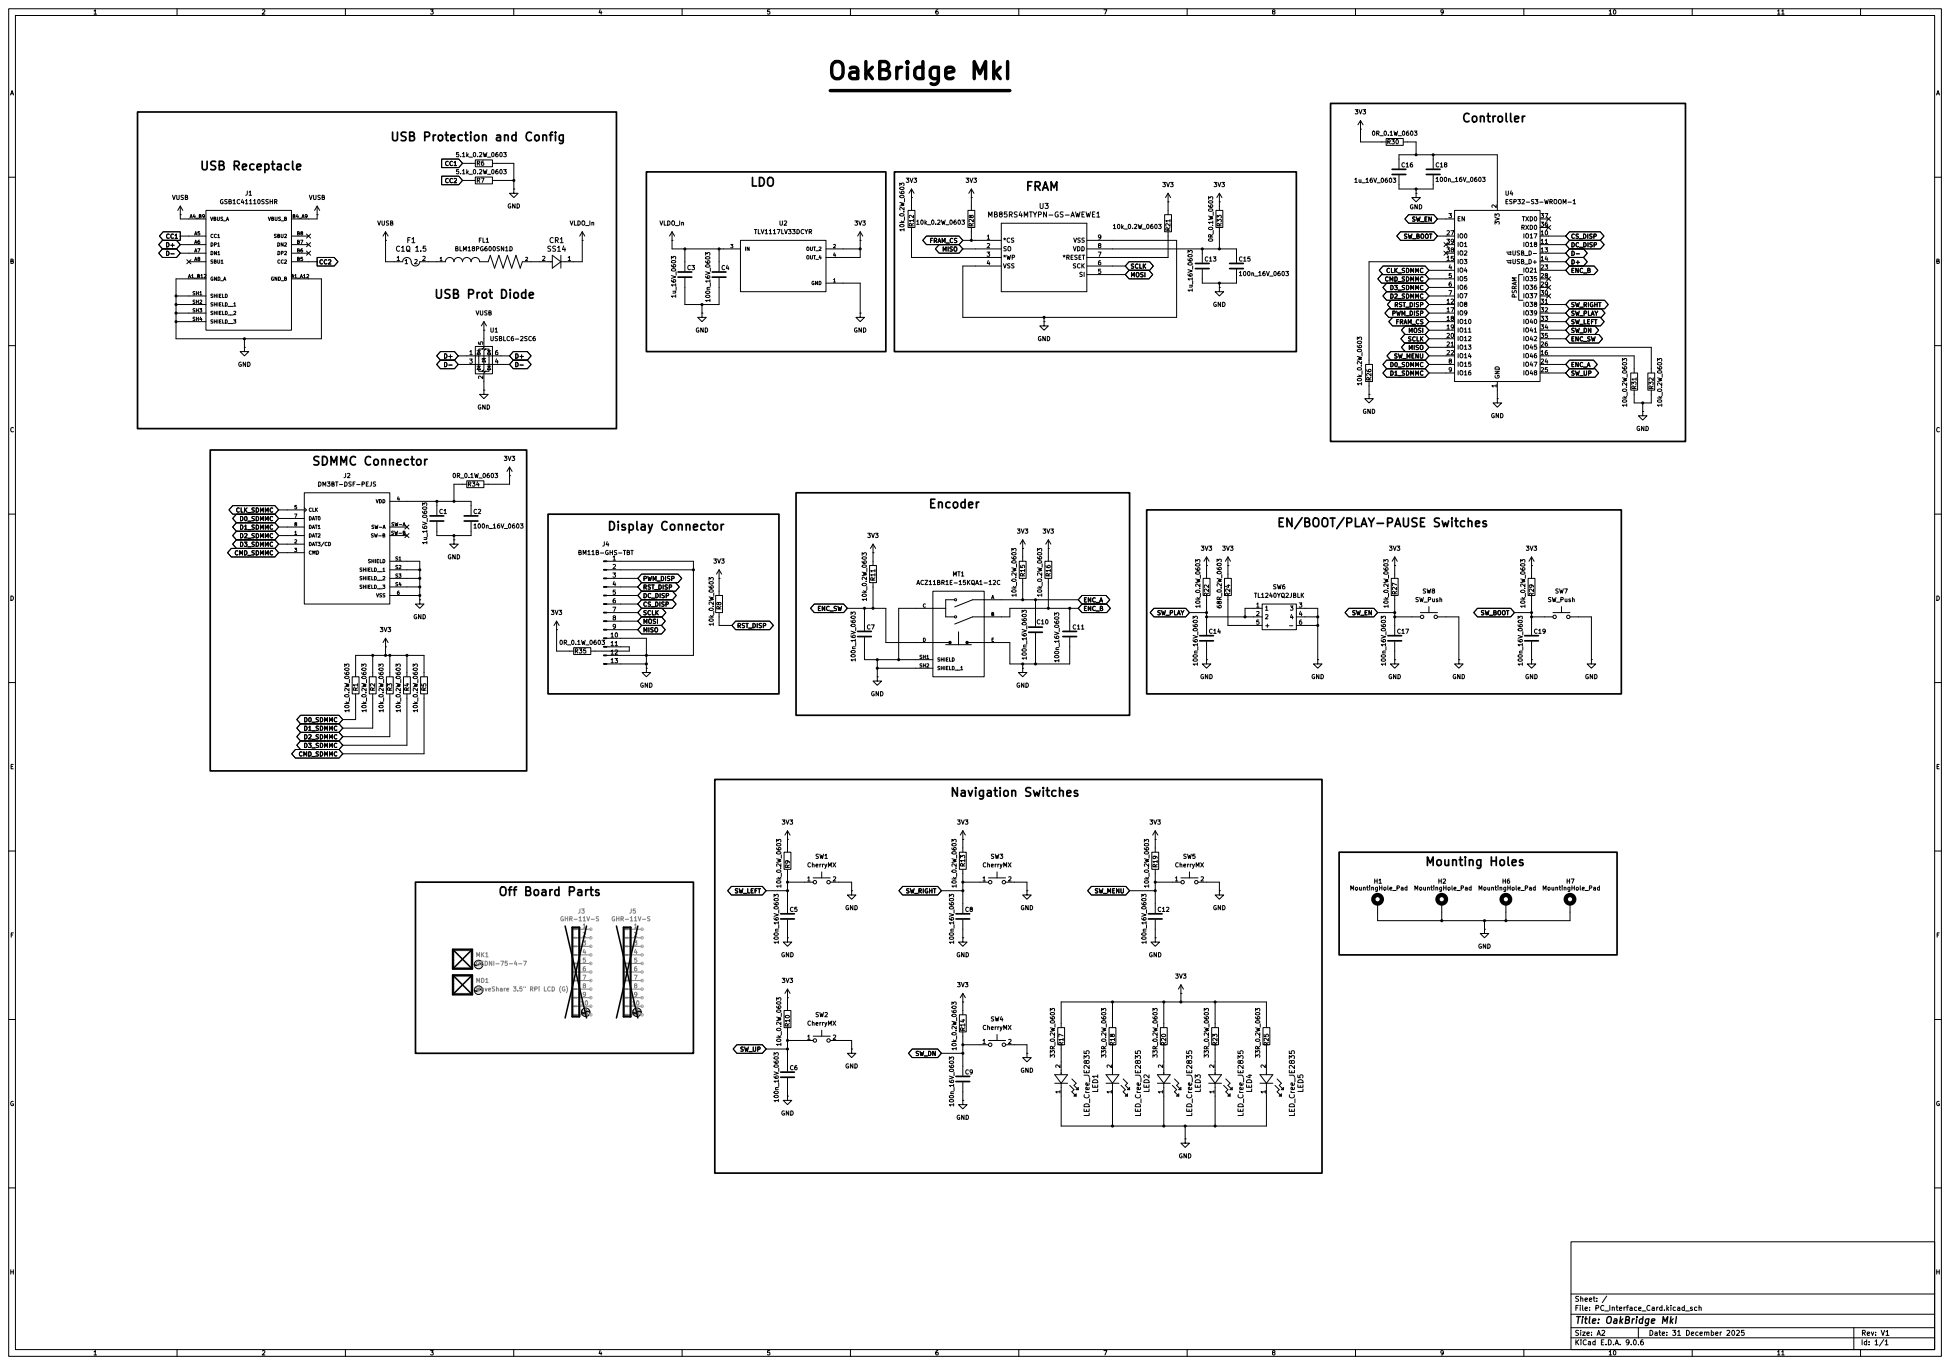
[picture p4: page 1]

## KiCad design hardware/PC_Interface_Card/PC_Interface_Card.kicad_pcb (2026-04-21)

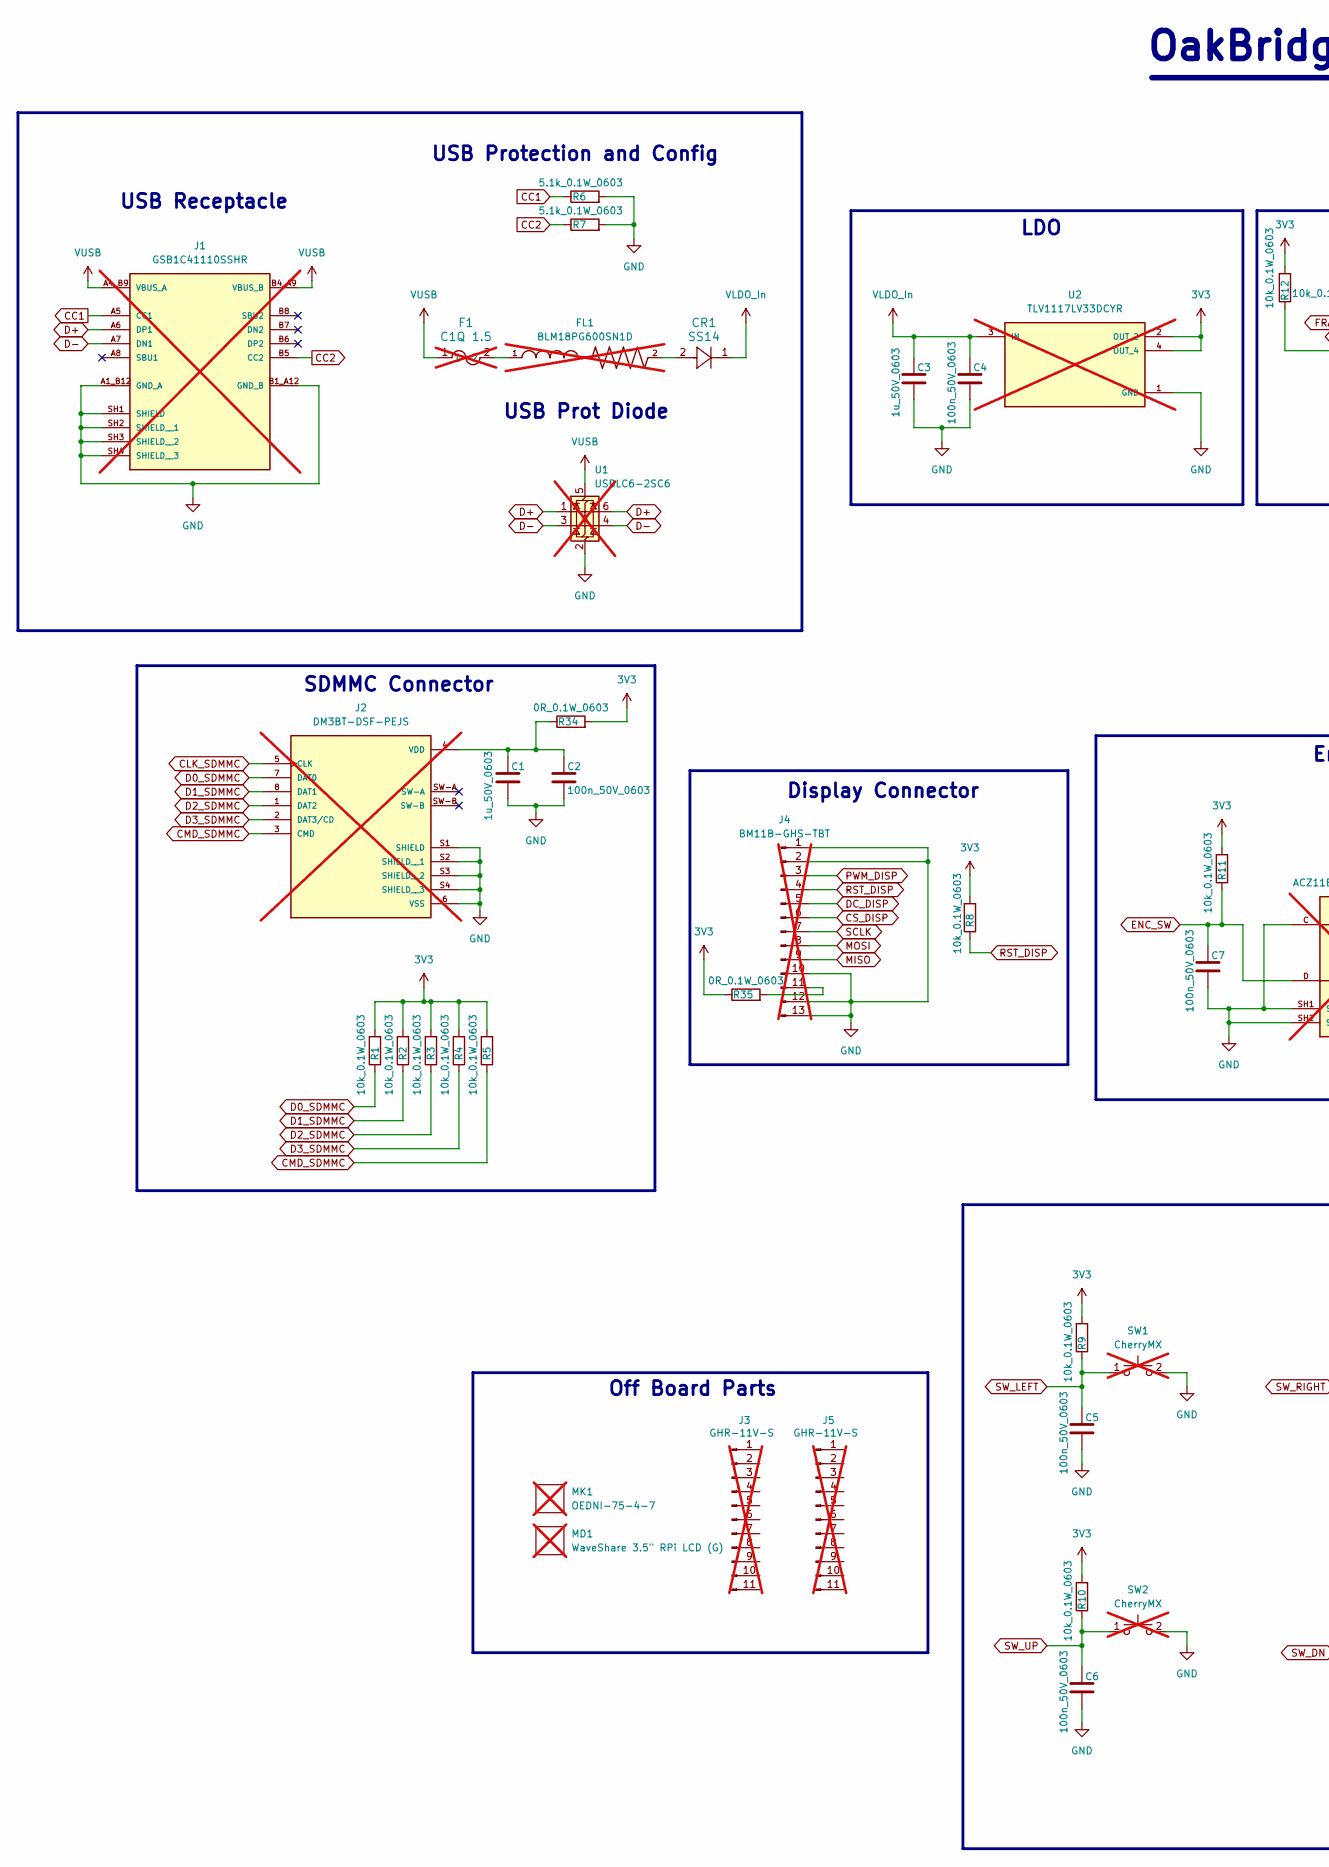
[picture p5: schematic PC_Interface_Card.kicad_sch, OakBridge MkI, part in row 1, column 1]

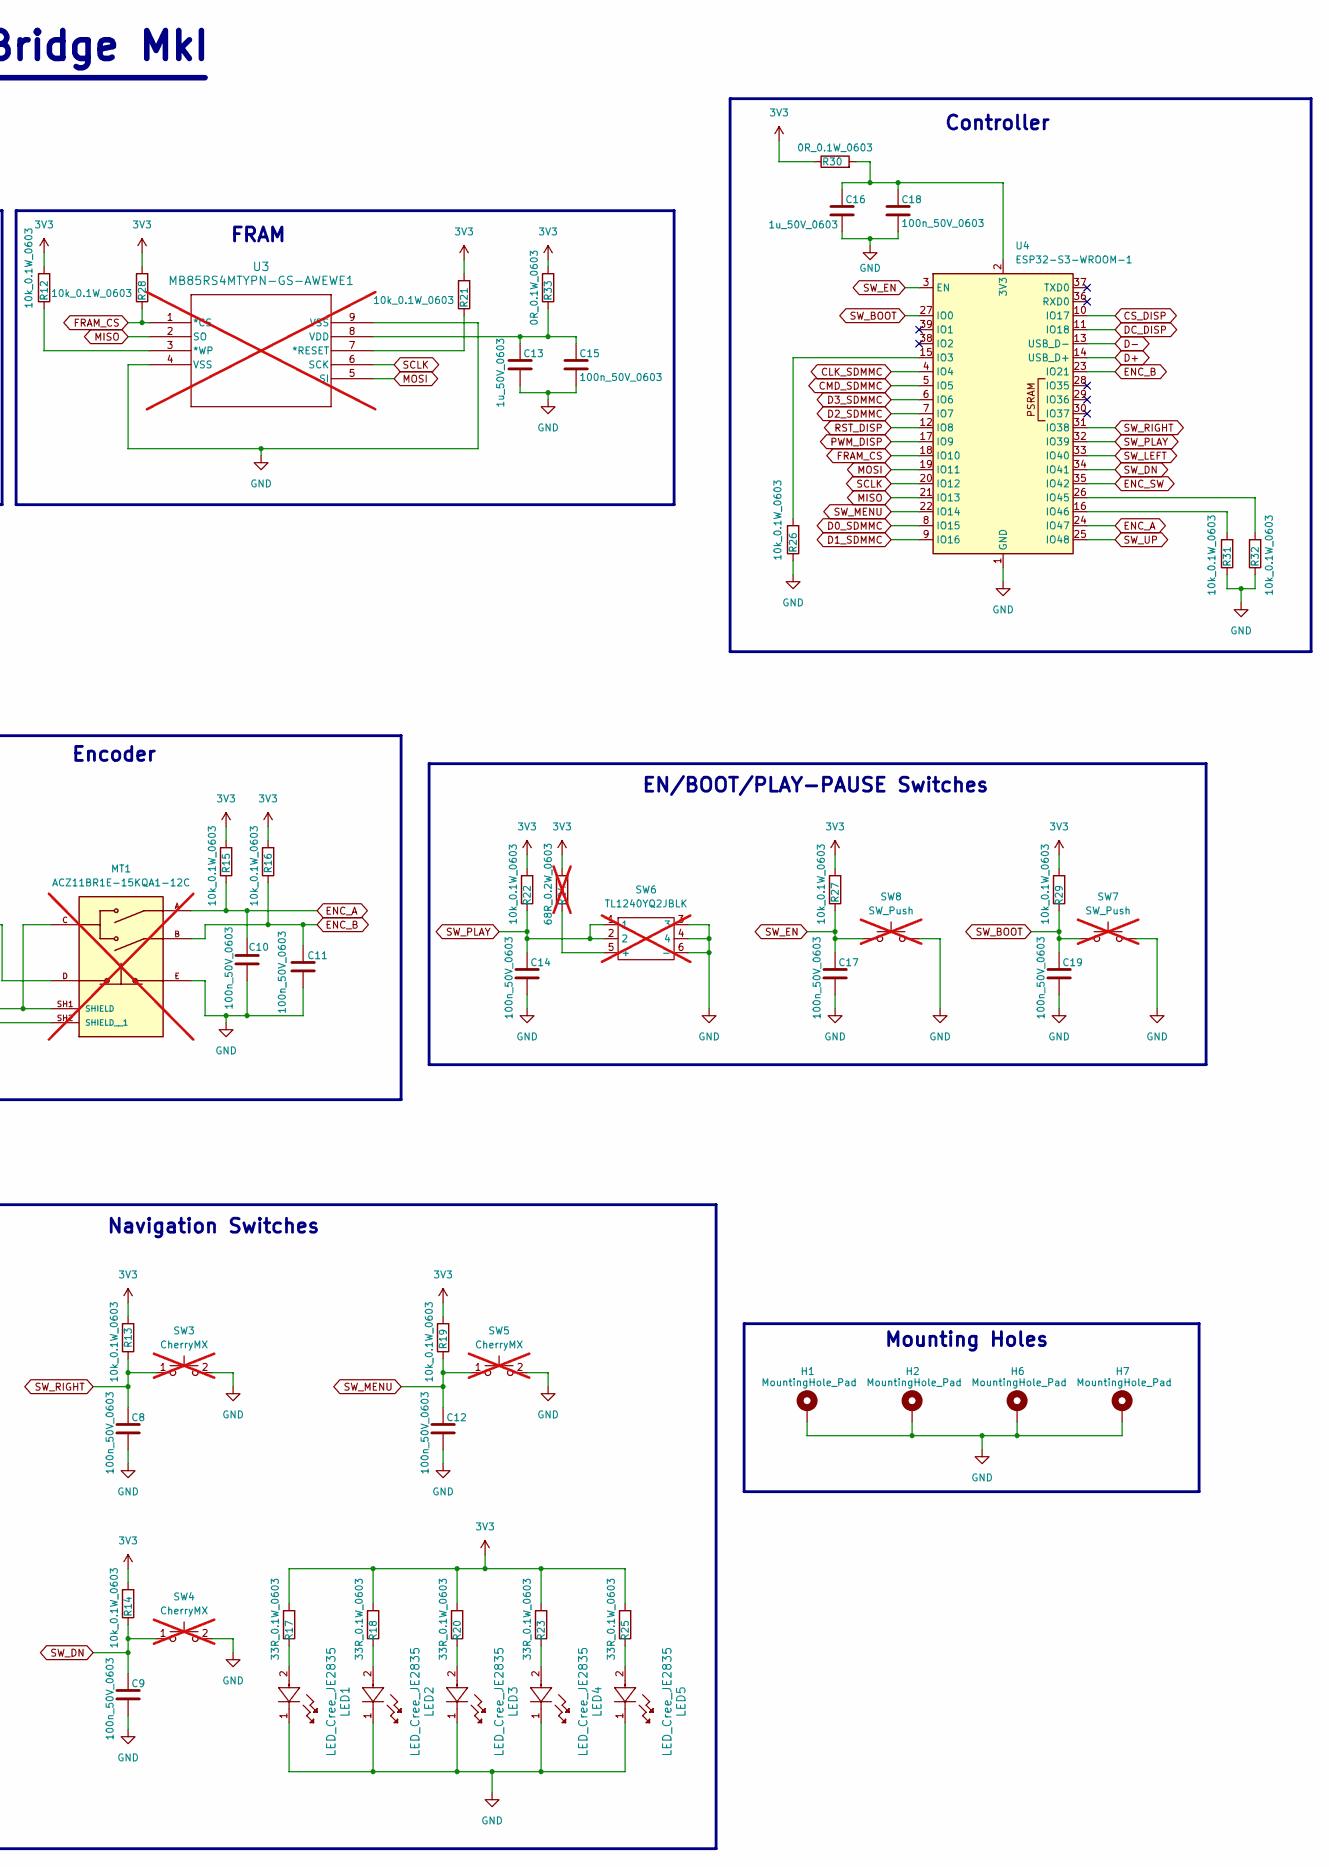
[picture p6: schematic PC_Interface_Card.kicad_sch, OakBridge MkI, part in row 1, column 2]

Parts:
C1, C3, C13, C16: 1u_50V_0603; C_0603_1608Metric; Manufacturer Part Number C0603C105K4RACTU; LCSC C15849
C2, C4, C5, C6, C7, C8, C9, C10, C11, C12, C14, C15, C17, C18, C19: 100n_50V_0603; C_0603_1608Metric; Manufacturer Part Number CC0603KRX7R7BB104; LCSC C14663
CR1: SS14; D_SMA; Manufacturer Part Number SS14; LCSC C2480
F1: C1Q 1.5; C1_BEL-M; Manufacturer Part Number C1Q 1.5; not fitted
FL1: BLM18PG600SN1D; BEAD_BLM18PG_C1608X95N; Manufacturer Part Number BLM18PG600SN1D; not fitted
H1, H2, H6, H7: MountingHole_Pad; MountingHole_2.2mm_M2_Pad_Via
J1: GSB1C41110SSHR; AMPHENOL_GSB1C41110SSHR; Manufacturer Part Number GSB1C41110SSHR; not fitted
J2: DM3BT-DSF-PEJS; HRS_DM3BT-DSF-PEJS; Manufacturer Part Number DM3BT-DSF-PEJS; not fitted
J3, J5: GHR-11V-S; Manufacturer Part Number GHR-11V-S; not fitted
J4: BM11B-GHS-TBT; CONN11_BM11B-GHS-TBTLFSNN_JST; Manufacturer Part Number BM11B-GHS-TBT; not fitted
LED1, LED2, LED3, LED4, LED5: LED_Cree_JE2835; LED_JE2835_CRW-M; Manufacturer Part Number JE2835ARY-N-0002A0000-N0000001
MD1: WaveShare 3.5" RPi LCD (G); Manufacturer Part Number 30897; not fitted
MK1: OEDNI-75-4-7; Manufacturer Part Number OEDNI-75-4-7; not fitted
MT1: ACZ11BR1E-15KQA1-12C; XDCR_ACZ11BR1E-15KQA1-12C; Manufacturer Part Number ACZ11BR1E-15KQA1-12C; not fitted
R1, R2, R3, R4, R5, R8, R9, R10, R11, R12, R13, R14, R15, R16, R19, R21, R22, R26, R27, R28, R29, R31, R32: 10k_0.1W_0603; R_0603_1608Metric; Manufacturer Part Number ERJ-PB3B1002V; LCSC C25804
R6, R7: 5.1k_0.1W_0603; R_0603_1608Metric; Manufacturer Part Number ERJ-PB3B5101V; LCSC C23186
R17, R18, R20, R23, R25: 33R_0.1W_0603; R_0603_1608Metric; Manufacturer Part Number CRGH0603J33R; LCSC C23140
R24: 68R_0.2W_0603; R_0603_1608Metric; Manufacturer Part Number RC0603FR-7W68RL; not fitted
R30, R33, R34, R35: 0R_0.1W_0603; R_0603_1608Metric; LCSC C21189
SW1, SW2, SW3, SW4, SW5: CherryMX; CherryMX_1.00u_PCB; Manufacturer Part Number MX2A-E1NA; not fitted
SW6: TL1240YQ2JBLK; TL1240YQ; Manufacturer Part Number TL1240YQ2JBLK; not fitted
SW7, SW8: SW_Push; SW_PUSH_6mm; not fitted
U1: USBLC6-2SC6; SOT-23-6; Manufacturer Part Number USBLC6-2SC6; not fitted
U2: TLV1117LV33DCYR; VREG_TLV1117LV33DCYR; Manufacturer Part Number TLV1117LV33DCYR; not fitted
U3: MB85RS4MTYPN-GS-AWEWE1; DFN8_FUJ-M; Manufacturer Part Number MB85RS4MTYPF-G-BCE1; not fitted
U4: ESP32-S3-WROOM-1; ESP32-S3-WROOM-1U; Manufacturer Part Number ESP32-S3-WROOM-1-N16R8; LCSC C2913202

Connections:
3V3: R1.2, R2.2, R3.2, R4.2, R5.2, R8.2, R9.2, R10.2, R11.2, R12.2, R13.2, R14.2, R15.2, R16.2, R17.2, R18.2, R19.2, R20.2, R21.2, R22.2, R23.2, R24.2, R25.2, R27.2, R28.2, R29.2, R30.1, R33.2, R34.2, R35.1, U2.2 (OUT_2), U2.4 (OUT_4)
CC1: J1.A5 (CC1), R6.1
CC2: J1.B5 (CC2), R7.1
CLK_SDMMC: J2.5 (CLK), U4.4 (IO4)
CMD_SDMMC: J2.3 (CMD), R5.1, U4.5 (IO5)
CS_DISP: J4.6, U4.10 (IO17)
D0_SDMMC: J2.7 (DAT0), R1.1, U4.8 (IO15)
D1_SDMMC: J2.8 (DAT1), R2.1, U4.9 (IO16)
D2_SDMMC: J2.1 (DAT2), R3.1, U4.7 (IO7)
D3_SDMMC: J2.2 (DAT3/CD), R4.1, U4.6 (IO6)
D+: J1.A6 (DP1), U1.1 (I/O1), U1.6 (I/O1), U4.14 (USB_D+)
D-: J1.A7 (DN1), U1.3 (I/O2), U1.4 (I/O2), U4.13 (USB_D-)
DC_DISP: J4.5, U4.11 (IO18)
ENC_A: C10.1, MT1.A, R15.1, U4.24 (IO47)
ENC_B: C11.1, MT1.B, R16.1, U4.23 (IO21)
ENC_SW: C7.1, MT1.D, R11.1, U4.35 (IO42)
FRAM_CS: R28.1, U3.1 (*CS), U4.18 (IO10)
GND: C1.2, C2.2, C3.2, C4.2, C5.2, C6.2, C7.2, C8.2, C9.2, C10.2, C11.2, C12.2, C13.2, C14.2, C15.2, C16.2, C17.2, C18.2, C19.2, H1.1 (1_1), H2.1 (1_1), H6.1 (1_1), H7.1 (1_1), J1.A1_B12 (GND_A), J1.B1_A12 (GND_B), J1.SH1 (SHIELD), J1.SH2 (SHIELD__1), J1.SH3 (SHIELD__2), J1.SH4 (SHIELD__3), J2.6 (VSS), J2.S1 (SHIELD), J2.S2 (SHIELD__1), J2.S3 (SHIELD__2), J2.S4 (SHIELD__3), J4.1, J4.2, J4.10, J4.12, J4.13, LED1.1, LED2.1, LED3.1, LED4.1, LED5.1, MT1.C, MT1.E, MT1.SH1 (SHIELD), MT1.SH2 (SHIELD__1), R6.2, R7.2, R26.1, R31.1, R32.1, SW1.2, SW2.2, SW3.2, SW4.2, SW5.2, SW6.3, SW6.4, SW6.6 (-), SW7.2, SW8.2, U1.2 (GND), U2.1 (GND), U3.4 (VSS), U3.9 (VSS), U4.1 (GND), U4.40 (GND), U4.41 (GND)
MISO: J4.9, U3.2 (SO), U4.21 (IO13)
MOSI: J4.8, U3.5 (SI), U4.19 (IO11)
unnamed: CR1.2, FL1.2
unnamed: F1.2, FL1.1
unnamed: C1.1, C2.1, J2.4 (VDD), R34.1
unnamed: J4.11, R35.2
unnamed: LED1.2, R17.1
unnamed: LED2.2, R18.1
unnamed: LED3.2, R20.1
unnamed: LED4.2, R23.1
unnamed: LED5.2, R25.1
unnamed: R24.1, SW6.5 (+)
unnamed: R21.1, U3.7 (*RESET)
unnamed: R12.1, U3.3 (*WP)
unnamed: C13.1, C15.1, R33.1, U3.8 (VDD)
unnamed: C16.1, C18.1, R30.2, U4.2 (3V3)
unnamed: R26.2, U4.15 (IO3)
unnamed: R32.2, U4.26 (IO45)
unnamed: R31.2, U4.16 (IO46)
PWM_DISP: J4.3, U4.17 (IO9)
RST_DISP: J4.4, R8.1, U4.12 (IO8)
SCLK: J4.7, U3.6 (SCK), U4.20 (IO12)
SW_BOOT: C19.1, R29.1, SW7.1, U4.27 (IO0)
SW_DN: C9.1, R14.1, SW4.1, U4.34 (IO41)
SW_EN: C17.1, R27.1, SW8.1, U4.3 (EN)
SW_LEFT: C5.1, R9.1, SW1.1, U4.33 (IO40)
SW_MENU: C12.1, R19.1, SW5.1, U4.22 (IO14)
SW_PLAY: C14.1, R22.1, SW6.1, SW6.2, U4.32 (IO39)
SW_RIGHT: C8.1, R13.1, SW3.1, U4.31 (IO38)
SW_UP: C6.1, R10.1, SW2.1, U4.25 (IO48)
VLDO_In: C3.1, C4.1, CR1.1, U2.3 (IN)
VUSB: F1.1, J1.A4_B9 (VBUS_A), J1.B4_A9 (VBUS_B), U1.5 (VBUS)

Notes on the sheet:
USB Protection and Config
USB Receptacle
Encoder
USB Prot Diode
Mounting Holes
LDO
OakBridge MkI
Navigation Switches
Display Connector
SDMMC Connector
Controller
Off Board Parts
EN/BOOT/PLAY-PAUSE Switches
FRAM

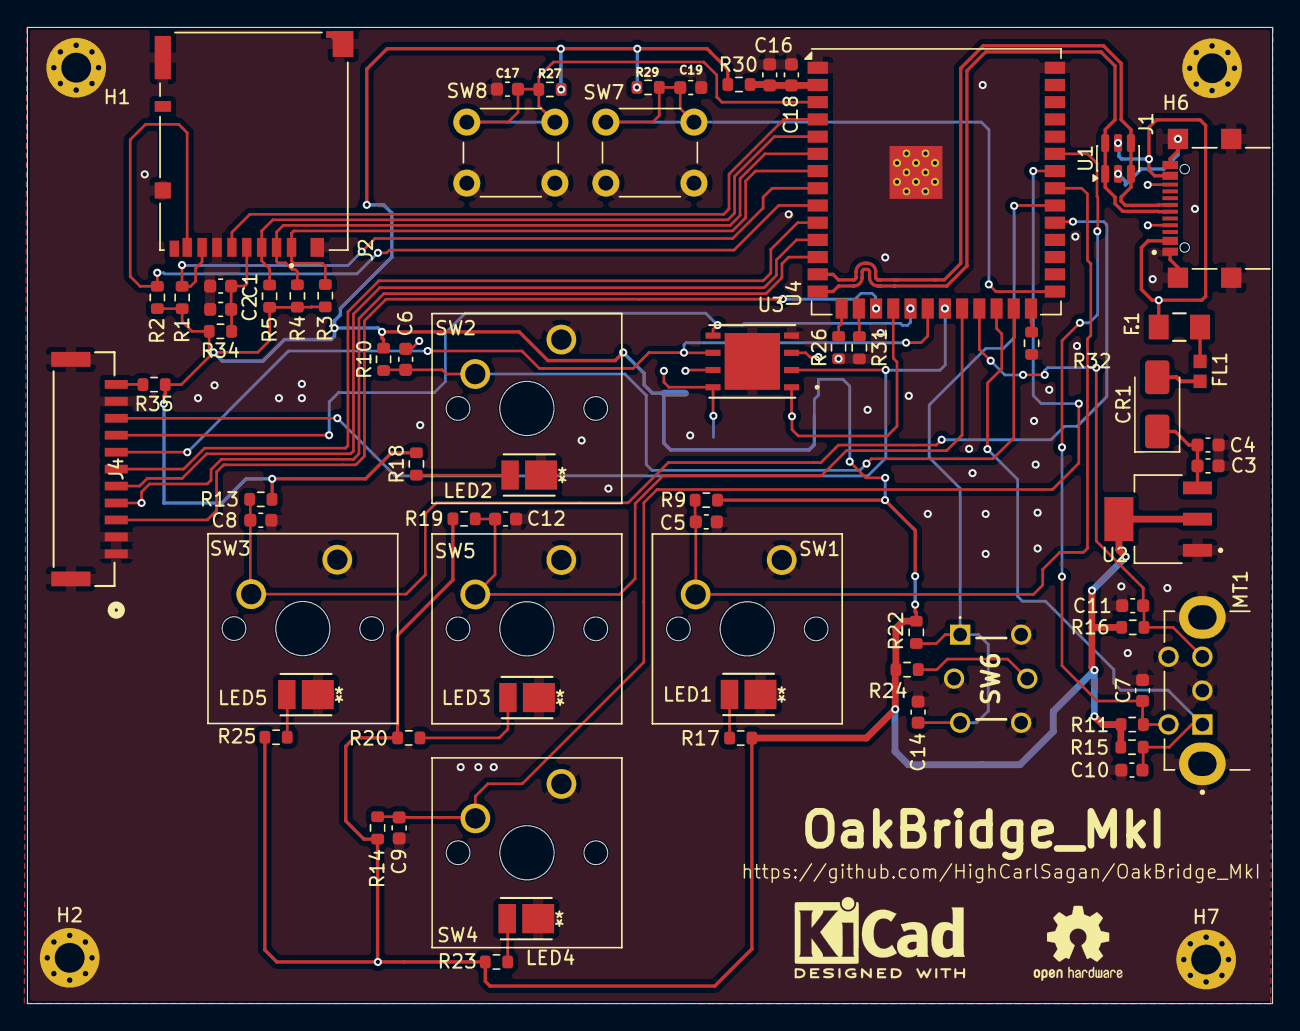
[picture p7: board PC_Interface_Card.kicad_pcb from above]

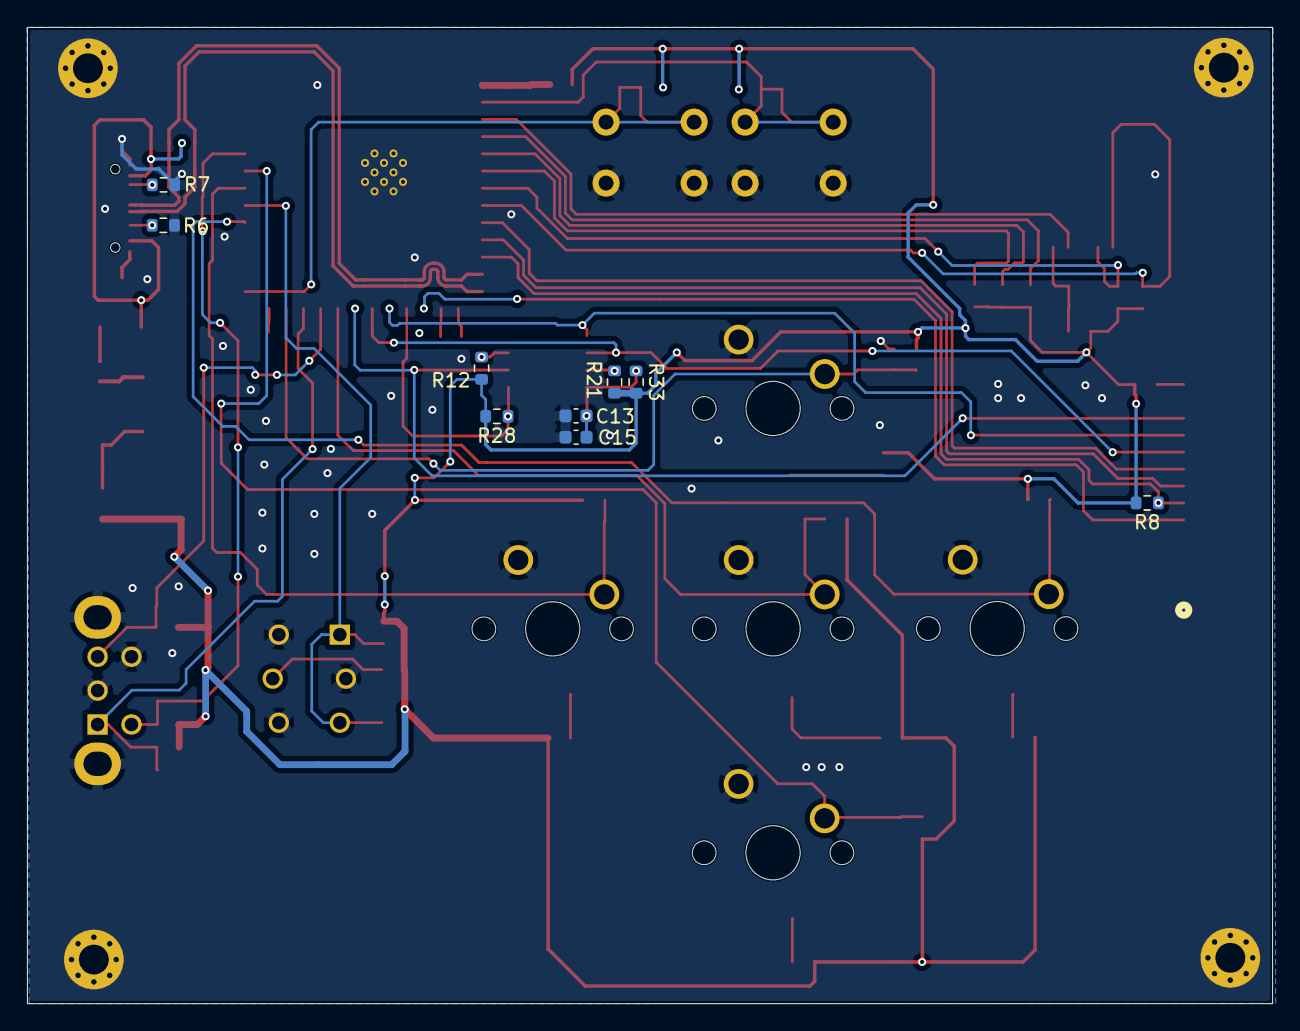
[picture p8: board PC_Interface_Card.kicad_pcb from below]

Board: 2 copper layers, 91.9 x 72.0 mm, 82 parts (9 on the bottom side), 50 nets.

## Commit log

2026-01-11 Updated final schematic, BoM and footprint assignment, imported schema to PCB
    [PC_Interface_Card.csv, PC_Interface_Card.kicad_pcb, PC_Interface_Card.kicad_sch]
2026-01-11 footprint and 3d model fixes, footprint mismatch persists for B3W-9000 still. Need a fix.
    [PC_Interface_Card.csv, PC_Interface_Card.kicad_pcb, PC_Interface_Card.kicad_sch]
2026-01-13 Schematic changes
    [PC_Interface_Card.kicad_sch]
2026-01-13 schematic pdf
2026-01-15 Footprints added with BoM update and all 3d models added.
    [PC_Interface_Card.csv, PC_Interface_Card.kicad_pcb, PC_Interface_Card.kicad_sch]
2026-01-15 More BoM fixes and 3D models, off board parts added.
    [PC_Interface_Card.csv, PC_Interface_Card.kicad_pcb, PC_Interface_Card.kicad_sch]
2026-01-15 Changed encoder to a right angle one
    [PC_Interface_Card.csv, PC_Interface_Card.kicad_pcb, PC_Interface_Card.kicad_sch]
2026-01-15 footprint fixes
    [PC_Interface_Card.csv, PC_Interface_Card.kicad_pcb, PC_Interface_Card.kicad_sch]
2026-01-16 Added via and trace rules
    [PC_Interface_Card.csv, PC_Interface_Card.kicad_pcb, PC_Interface_Card.kicad_sch]
2026-01-24 Start of day work - 24/01
    [PC_Interface_Card.csv, PC_Interface_Card.kicad_pcb, PC_Interface_Card.kicad_sch]
2026-01-24 Saving data for the day - added dxf for display and component placement
    [PC_Interface_Card.kicad_pcb]
2026-01-24 Alignment of moounting holes and final layout
    [PC_Interface_Card.kicad_pcb, PC_Interface_Card.kicad_sch]
2026-01-25 More layout work - Display SPI and differential pair DRC pending
    [PC_Interface_Card.kicad_pcb]
2026-01-25 More alyout work, added DRC Error output for 26012026
    [PC_Interface_Card.kicad_sch]
2026-02-01 layout changes
    [PC_Interface_Card.csv, PC_Interface_Card.kicad_pcb, PC_Interface_Card.kicad_sch]
2026-02-06 Saving work with smaller board changes
    [PC_Interface_Card.kicad_pcb]
2026-02-06 Some DRC errors remain - clarifications on Monday then fab
    [PC_Interface_Card.csv, PC_Interface_Card.kicad_pcb, PC_Interface_Card.kicad_sch]
2026-02-15 Manufacturing Readiness
    [PC_Interface_Card-B_Cu.gbr, PC_Interface_Card-B_Mask.gbr, PC_Interface_Card-B_Paste.gbr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]
2026-04-21 MkII ready to fab but SMD via error still coming on JLCPCB gerber viewer - need to figure out why and close
    [PC_Interface_Card-B_Cu.gbr, PC_Interface_Card-B_Mask.gbr, PC_Interface_Card-B_Paste.gbr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]

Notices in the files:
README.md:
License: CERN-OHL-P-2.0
